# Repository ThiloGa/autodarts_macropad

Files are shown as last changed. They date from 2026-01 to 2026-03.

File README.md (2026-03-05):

<div align="center">
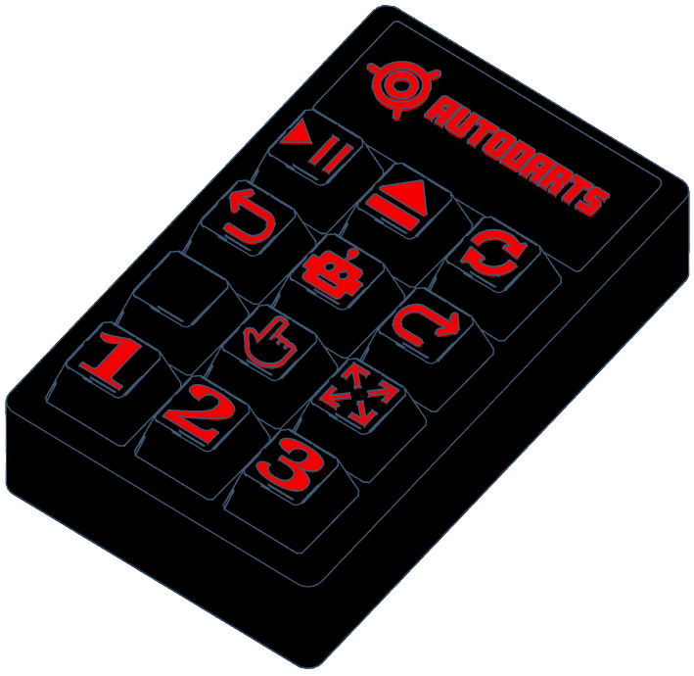
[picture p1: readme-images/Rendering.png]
3D-Modell
    
  
  <h1>🎯 Macropad for Autodarts</h1>
  <p><b>✨ The ultimate DIY wireless companion for your Autodarts setup ✨</b></p>
  <p><i>A custom 12-key controller designed for seamless darts tracking.</i></p>

  <p>
    The Macropad for Autodarts is a wireless DIY controller featuring 12 mechanical keys, specifically designed for comfortable operation of the Autodarts software directly from the oche. It provides instant access to functions such as undoing throws, switching cameras, or calling the AI referee, while offering an impressive battery life of about six weeks via Bluetooth. Thanks to its open-source firmware, the entire device is fully customizable to suit your personal needs.
  </p>

  <p>
    
    
    
  </p>

  <p>
    <a href="#features-en">🚀 Features</a> •
    <a href="#manual-en">📖 Manual</a> •
    <a href="#diagrams-en">🗺️ Wiring & Pinout</a> •
    <a href="#keymap-en">🎹 Keymap</a> •
    <a href="#bom-en">📦 BOM</a> •
    <a href="#operation-en">💡 Troubleshooting</a> •
    <a href="#support-en">☕ Support</a>
  </p>
</div>

<hr />

<h2 id="features-en">🚀 Key Features</h2>
<ul>
  <li><b>📶 True Wireless:</b> Low-energy Bluetooth 5.0 connectivity via the nRF52840 controller for a cable-free oche. 🎯</li>
  <li><b>🔋 Massive Battery Life:</b> Operates for up to <b>6 weeks</b> on a single charge. The integrated deep-sleep mode further preserves battery life. ⚡</li>
  <li><b>⌨️ Superior Tactile Feedback:</b> 12 mechanical Gateron G Pro 3.0 switches provide a high-quality actuation point for reliable inputs. ⌨️</li>
  <li><b>☁️ Cloud Configuration:</b> Customize your keymap directly in the browser via GitHub Actions—no local coding environment required. ☁️</li>
  <li><b>🖥️ OS Integration:</b> Battery percentage is reported natively and can be viewed in Windows or Linux system settings. 🖥️</li>
</ul>

<hr />

<h2 id="manual-en">📖 Comprehensive Manual</h2>
<p>
  This repository includes a <b>detailed 32-page PDF instruction manual</b>. It covers the entire process: from optimized 3D printing settings and complex matrix soldering to flashing the ZMK firmware and customized key mapping.
  <br><br>
  👉 <b>View the Instructions here:</b> <a href="https://github.com/mrcl-rckl/autodarts_macropad/blob/main/instructions/0_EN_Instructions.pdf">0_EN_Instructions.pdf</a>
  <br>
  👉 <b>3D Models on Printables:</b> <a href="https://www.printables.com/model/1576041-autodarts-macropad">Printables.com</a>
  <br>
  👉 <b>3D Models on MakerWorld:</b> <a href="https://makerworld.com/de/models/2319788-autodarts-macropad">MakerWorld.com</a>
</p>

<hr />

<h2 id="bom-en">📦 Bill of Materials (BOM)</h2>
<p>This project is designed for experienced makers and involves 3D printing, component assembly, and precision soldering. 🛠️</p>
<table>
  <thead>
    <tr>
      <th>Qty</th>
      <th>Component 🛒</th>
      <th>Source 🔗</th>
    </tr>
  </thead>
  <tbody>
    <tr>
      <td>12x</td>
      <td><b>Gateron G Pro 3.0 Switches</b></td>
      <td><a href="https://de.aliexpress.com/item/1005007052507996.html">AliExpress</a></td>
    </tr>
    <tr>
      <td>1x</td>
      <td><b>nRF52840 Developer Board (SuperMini)</b></td>
      <td><a href="https://de.aliexpress.com/item/1005008664621573.html">AliExpress</a></td>
    </tr>
    <tr>
      <td>1x</td>
      <td><b>500mAh LiPo Battery (503030)</b></td>
      <td><a href="https://de.aliexpress.com/item/1005007964712378.html">AliExpress</a></td>
    </tr>
    <tr>
      <td>12x</td>
      <td><b>1N4148 Diodes</b></td>
      <td><a href="https://de.aliexpress.com/item/1005006208000285.html">AliExpress</a></td>
    </tr>
    <tr>
      <td>16x</td>
      <td><b>Jumper Wires Female (20-30cm)</b></td>
      <td><a href="https://de.aliexpress.com/item/1005007046465880.html">AliExpress</a></td>
    </tr>
    <tr>
      <td>1x</td>
      <td><b>Toggle Switch (MTS-101)</b></td>
      <td><a href="https://de.aliexpress.com/item/1005009744920784.html">AliExpress</a></td>
    </tr>
    <tr>
      <td>1x</td>
      <td><b>ASUS USB-BT500 Bluetooth Dongle</b></td>
      <td><a href="https://www.cyberport.de/pc-und-zubehoer/netzwerk/bluetooth/asus/pdp/4e18-007/asus-usb-bt500-bluetooth-5-0-usb-adapter.html">Cyberport</a></td>
    </tr>
  </tbody>
</table>

<h3>🛠️ Required Tools & Additional Materials</h3>
<ul>
  <li>USB-C charging cable</li>
  <li>Soldering iron & Solder wire</li>
  <li>Hot air gun or lighter (for insulation)</li>
  <li>Heat shrinks & side cutters</li>
  <li>Pliers & wire stripping tool</li>
  <li>Super glue (for mounting logos)</li>
  <li>Filament (PLA or PETG - 2 colors recommended)</li>
</ul>

<hr />

<h2 id="diagrams-en">🗺️ Wiring Diagram & Pinout</h2>
<div align="center">
  <h3>🛠️ Wiring Diagram</h3>
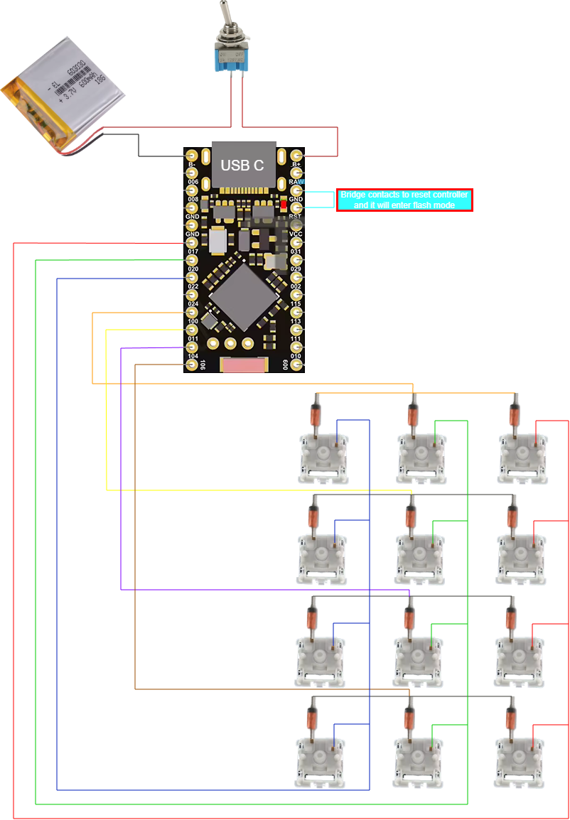
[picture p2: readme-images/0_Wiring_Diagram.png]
Wiring Diagram
  
  <br><br>
  <h3>🔌 Controller Pinout</h3>
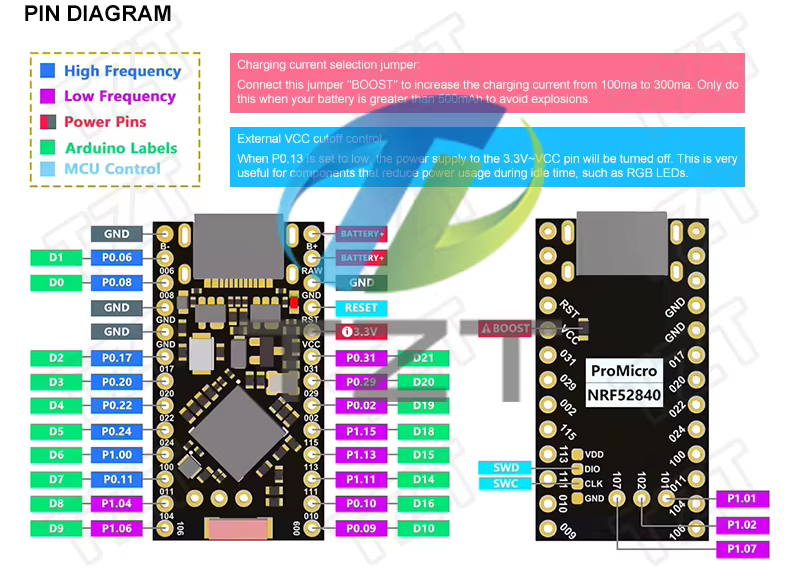
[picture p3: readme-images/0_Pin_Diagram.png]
Pin Diagram
  
</div>

<hr />

<h2 id="keymap-en">🎹 Default Key Assignment</h2>
<p>The layout is fully optimized for the Autodarts web interface commands. 🎯</p>

<div align="center">
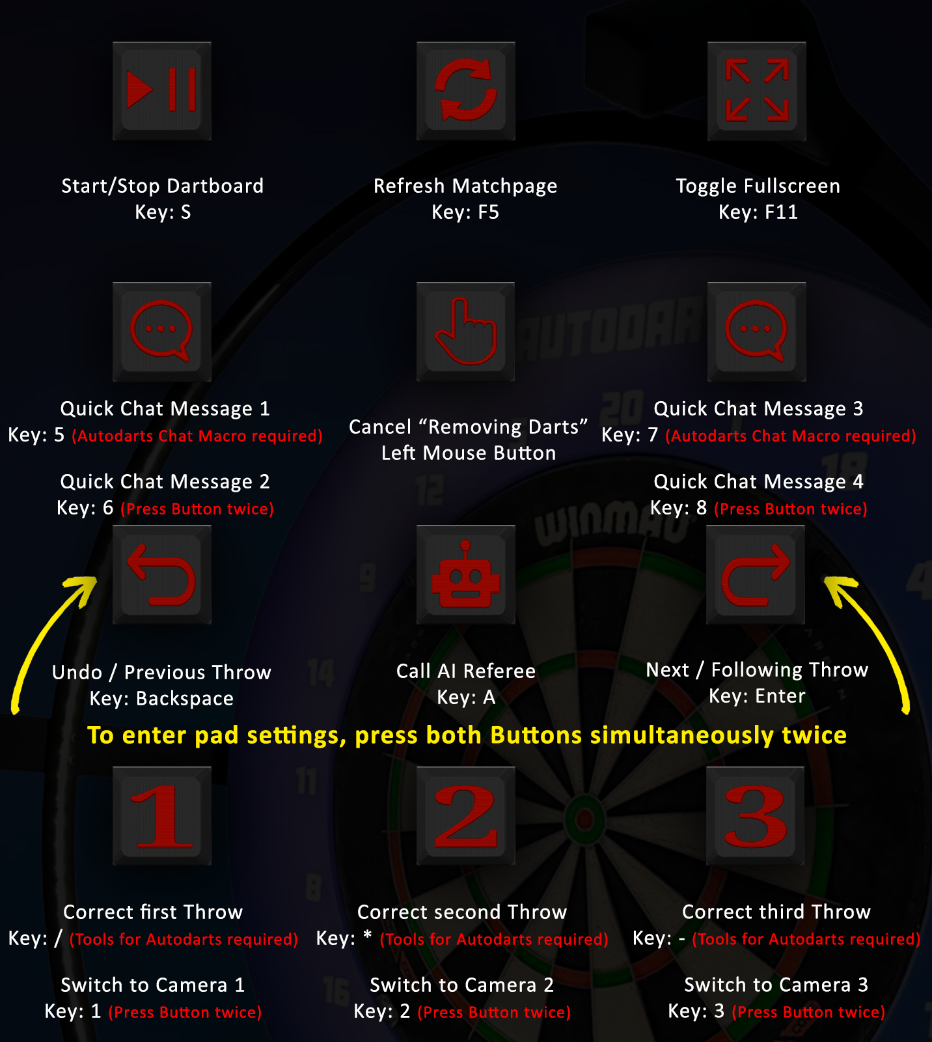
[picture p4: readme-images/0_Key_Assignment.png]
Keymap Assignment
  
</div>

<div align="center">
  Quick Corretion
</div>

<div align="center">
  Settings
</div>

<br>

<hr />

<h2 id="operation-en">💡 Operation & Troubleshooting</h2>
<ul>
  <li><b>Charging:</b> The physical toggle switch <b>MUST be in the ON position</b> to charge the battery via USB-C. 🔌</li>
  <li><b>Pairing Reset:</b> To clear existing Bluetooth bonds, press <b>[Arrow Left] + [Arrow Right]</b> keys simultaneously twice. 🔄</li>
  <li><b>Bootloader Mode:</b> If the device is not recognized as a drive, bridge the <b>GND</b> and <b>RST</b> pins twice quickly while connected to the PC. 💾</li>
  <li><b>Input Focus:</b> Ensure the browser window is "in focus" (clicked) for Autodarts to register key presses. 🎯</li>
</ul>

<hr />

<h2 id="support-en">☕ Support</h2>
<p align="left">
  If this project helped you hit the bullseye, consider supporting my work! 🎯☕
  <br><br>
  <a href="https://www.buymeacoffee.com/mrcl_rckl">
    Buy Me A Coffee
  </a>
</p>

<hr />
<br><br>

<br><br>
<hr />

<div align="center">
  <h1>🎯 Zusatztastatur für Autodarts</h1>
  <p><b>✨ Der ultimative kabellose Begleiter für dein Autodarts-Setup – Marke Eigenbau ✨</b></p>
  <p><i>Ein maßgeschneidertes 12-Tasten-Steuergerät für die professionelle Wurferfassung am Oche.</i></p>

  <p>
    Das Macropad für Autodarts ist ein kabelloses DIY-Steuergerät mit 12 mechanischen Tasten, das speziell für die komfortable Bedienung der Autodarts-Software direkt am Oche entwickelt wurde. Es ermöglicht den blitzschnellen Zugriff auf Funktionen wie Wurfrücknahme, Kamerawechsel oder den KI-Schiedsrichter und bietet dank Bluetooth-Anbindung eine beachtliche Akkulaufzeit von etwa sechs Wochen. Durch die Nutzung von Open-Source-Firmware lässt sich das gesamte Gerät zudem vollständig nach deinen persönlichen Wünschen anpassen.
  </p>

  <p>
    
    
    
  </p>

  <p>
    <a href="#features-de">🚀 Funktionen</a> •
    <a href="#manual-de">📖 Anleitung</a> •
    <a href="#diagrams-de">🗺️ Schaltplan & Pinbelegung</a> •
    <a href="#keymap-de">🎹 Tastenbelegung</a> •
    <a href="#bom-de">📦 Stückliste</a> •
    <a href="#operation-de">💡 Fehlerbehebung</a> •
    <a href="#support-de">☕ Unterstützung</a>
  </p>
</div>

<hr />

<h2 id="features-de">🚀 Hauptmerkmale</h2>
<ul>
  <li><b>📶 Vollkommen Kabellos:</b> Dank Bluetooth 5.0 und dem nRF52840-Steuermodul bleibt dein Abwurfbereich frei von Kabeln. 🎯</li>
  <li><b>🔋 Enorme Akkulaufzeit:</b> Eine einzige Ladung hält bei normaler Nutzung bis zu <b>6 Wochen</b>. Der integrierte Tiefschlafmodus schont die Batterie zusätzlich. ⚡</li>
  <li><b>⌨️ Hochwertiger Druckpunkt:</b> 12 mechanische Gateron G Pro 3.0 Schalter bieten ein erstklassiges haptisches Feedback und garantieren eine zuverlässige Bedienung. ⌨️</li>
  <li><b>☁️ Cloud-Konfiguration:</b> Die Tastenbelegung kann direkt im Browser über GitHub-Automatisierungen angepasst werden – es ist keine lokale Programmierumgebung erforderlich. ☁️</li>
  <li><b>🖥️ System-Integration:</b> Der Akkustand wird direkt in den Einstellungen von Windows oder Linux angezeigt. 🖥️</li>
</ul>

<hr />

<h2 id="manual-de">📖 Umfangreiche Anleitung</h2>
<p>
  In diesem Projektarchiv findest du eine <b>detaillierte 32-seitige PDF-Anleitung</b>. Diese führt dich Schritt für Schritt durch den gesamten Prozess: von den optimalen Einstellungen für den 3D-Druck über das präzise Verlöten der Tastatur-Matrix bis hin zur Installation der Steuersoftware und der persönlichen Tastenbelegung.
  <br><br>
  👉 <b>Hier zur Anleitung:</b> <a href="https://github.com/mrcl-rckl/autodarts_macropad/blob/main/instructions/0_DE_Anleitung.pdf">0_DE_Anleitung.pdf</a>
  <br>
  👉 <b>3D-Modelle auf Printables:</b> <a href="https://www.printables.com/model/1576041-autodarts-macropad">Printables.com</a>
  <br>
  👉 <b>3D-Modelle auf MakerWorld:</b> <a href="https://makerworld.com/de/models/2319788-autodarts-macropad">MakerWorld.com</a>
</p>

<hr />

<h2 id="bom-de">📦 Stückliste</h2>
<p>Dieses Projekt wird für erfahrene Bastler empfohlen, da es fundierte Kenntnisse im 3D-Druck und im Weichlöten voraussetzt. 🛠️</p>
<table>
  <thead>
    <tr>
      <th>Menge</th>
      <th>Bauteil 🛒</th>
      <th>Bezugsquelle 🔗</th>
    </tr>
  </thead>
  <tbody>
    <tr>
      <td>12x</td>
      <td><b>Gateron G Pro 3.0 Tastenschalter</b></td>
      <td><a href="https://de.aliexpress.com/item/1005007052507996.html">AliExpress</a></td>
    </tr>
    <tr>
      <td>1x</td>
      <td><b>nRF52840 Entwickler-Platine (SuperMini)</b></td>
      <td><a href="https://de.aliexpress.com/item/1005008664621573.html">AliExpress</a></td>
    </tr>
    <tr>
      <td>1x</td>
      <td><b>500mAh LiPo Akku (Bauform 503030)</b></td>
      <td><a href="https://de.aliexpress.com/item/1005007964712378.html">AliExpress</a></td>
    </tr>
    <tr>
      <td>12x</td>
      <td><b>1N4148 Dioden</b></td>
      <td><a href="https://de.aliexpress.com/item/1005006208000285.html">AliExpress</a></td>
    </tr>
    <tr>
      <td>16x</td>
      <td><b>Steckbrückenkabel (weiblich, 20-30cm)</b></td>
      <td><a href="https://de.aliexpress.com/item/1005007046465880.html">AliExpress</a></td>
    </tr>
    <tr>
      <td>1x</td>
      <td><b>Kippschalter (MTS-101)</b></td>
      <td><a href="https://de.aliexpress.com/item/1005009744920784.html">AliExpress</a></td>
    </tr>
    <tr>
      <td>1x</td>
      <td><b>ASUS USB-BT500 Bluetooth-Adapter</b></td>
      <td><a href="https://www.cyberport.de/pc-und-zubehoer/netzwerk/bluetooth/asus/pdp/4e18-007/asus-usb-bt500-bluetooth-5-0-usb-adapter.html">Cyberport</a></td>
    </tr>
  </tbody>
</table>

<h3>🛠️ Erforderliche Werkzeuge & Materialien</h3>
<ul>
  <li>USB-C Ladekabel</li>
  <li>Lötkolben & Lötzinn</li>
  <li>Heißluftfön oder Feuerzeug (für die Isolierung der Kontakte)</li>
  <li>Schrumpfschläuche & Seitenschneider</li>
  <li>Zange & Abisolierwerkzeug</li>
  <li>Sekundenkleber (zum Fixieren der Logos)</li>
  <li>Filament (PLA oder PETG - 2 verschiedene Farben für Kontrast-Optik empfohlen)</li>
</ul>

<hr />

<h2 id="diagrams-de">🗺️ Stromlaufplan & Anschlussbelegung</h2>
<div align="center">
  <h3>🛠️ Schaltplan der Tastatur-Matrix</h3>
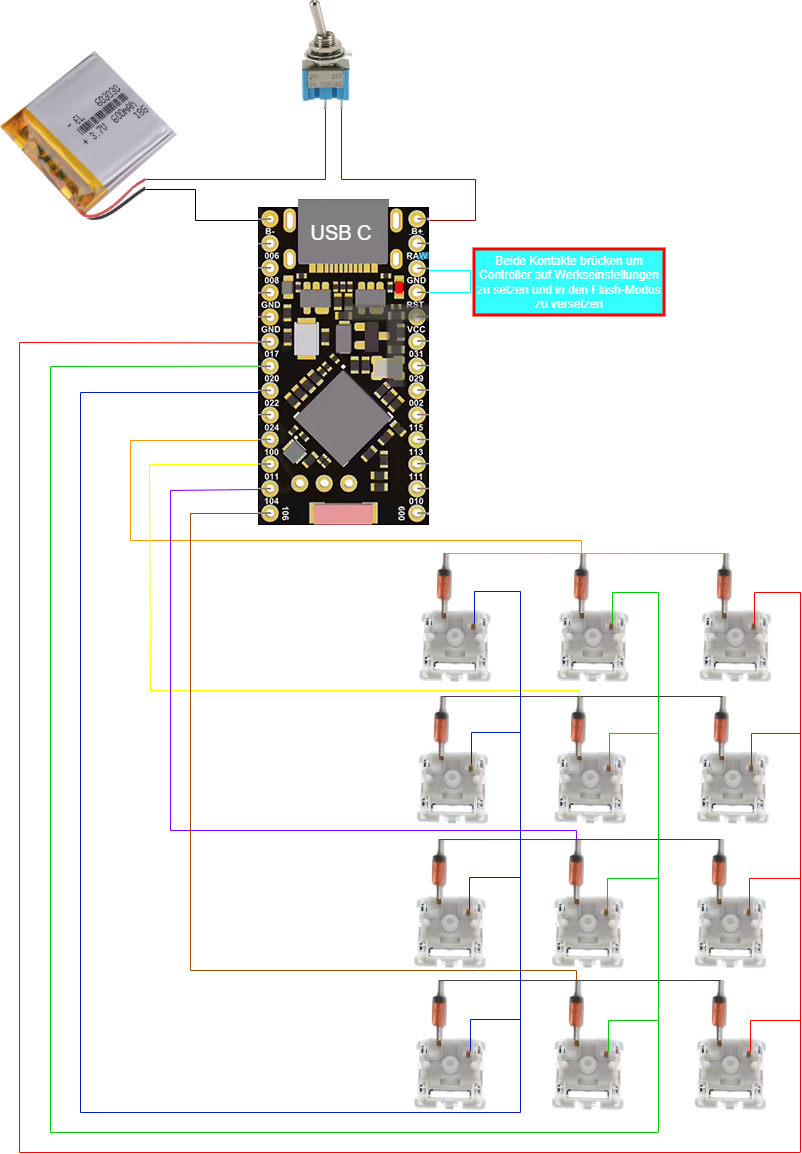
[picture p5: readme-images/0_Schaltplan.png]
Stromlaufplan
  
  <br><br>
  <h3>🔌 Anschlussbelegung des Steuerungsmoduls</h3>
  Anschlussbelegung
</div>

<hr />

<h2 id="keymap-de">🎹 Standard-Tastenbelegung</h2>
<p>Die Tasten sind für die Autodarts-Weboberfläche optimiert, damit du dich voll auf deine Würfe konzentrieren kannst. 🎯</p>

<div align="center">
  Tastenbelegung
</div>

<div align="center">
  Schnell-Korrekur
</div>

<div align="center">
  Einstellungen
</div>

<br>

<hr />

<h2 id="operation-de">💡 Bedienung & Fehlerbehebung</h2>
<ul>
  <li><b>Ladevorgang:</b> Der physische Kippschalter <b>MUSS auf EIN (ON)</b> stehen, damit der Akku über USB-C geladen werden kann. 🔌</li>
  <li><b>Verbindung zurücksetzen:</b> Um die Bluetooth-Kopplung zu löschen, die Tasten <b>[Pfeil Links] + [Pfeil Rechts]</b> gleichzeitig zweimal drücken. 🔄</li>
  <li><b>Bootloader-Modus:</b> Falls die Platine nicht als Laufwerk erkannt wird, überbrücke kurz zweimal hintereinander die Kontakte <b>GND</b> und <b>RST</b>. 💾</li>
  <li><b>Eingabe-Fokus:</b> Das Browserfenster muss aktiv sein („im Fokus“), damit Autodarts die Tastaturbefehle registriert. 🎯</li>
</ul>

<hr />

<h2 id="support-de">☕ Unterstützung</h2>
<p align="left">
  Hat dieses Projekt bei dir ins Schwarze getroffen? Wenn du meine Arbeit unterstützen möchtest, freue ich mich über einen digitalen Kaffee! Jeder Beitrag fließt direkt in die Entwicklung neuer Prototypen und quelloffener Werkzeuge für die Community. 🎯☕
  <br><br>
  <a href="https://www.buymeacoffee.com/mrcl_rckl">
    Spende mir einen Kaffee
  </a>
</p>

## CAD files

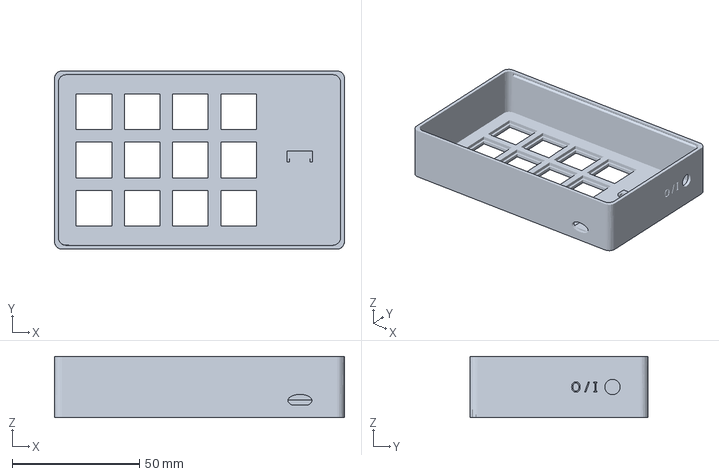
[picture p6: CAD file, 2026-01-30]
3d-printing-files/1_Case.3mf
113.8 x 70.0 x 24.0 mm

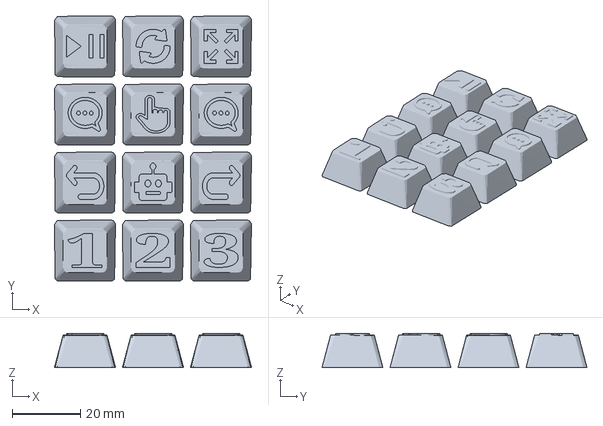
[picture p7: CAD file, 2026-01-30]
3d-printing-files/3_Keycaps_Gateron_Pro_3.3mf
58.0 x 77.9 x 10.0 mm

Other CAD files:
3d-printing-files/1_Case.stl
3d-printing-files/3_Keycaps_Gateron_Pro_3.stl

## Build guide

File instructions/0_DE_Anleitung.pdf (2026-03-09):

Deutsch

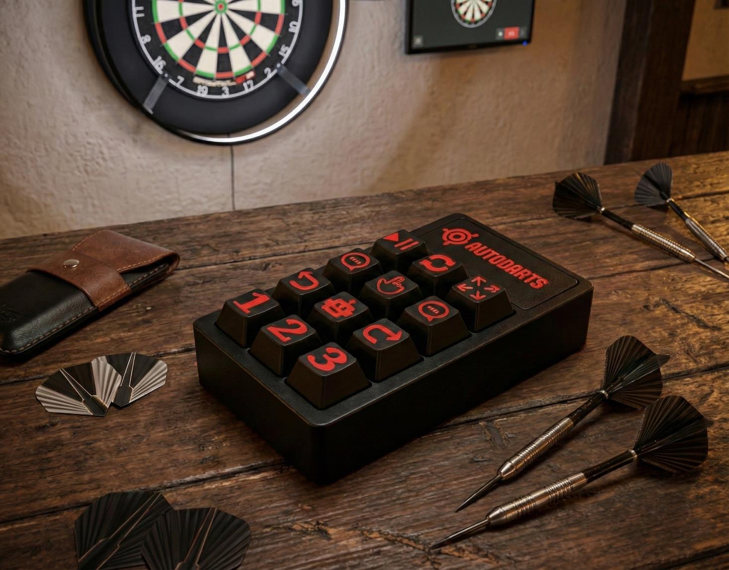
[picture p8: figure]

Autor: mrcl-rckl | 1 | Version: 1.0

# DIY: 12-Tasten-Makropad für Autodarts

Schwierigkeitsgrad: Empfohlen für erfahrene Hersteller

Erfordert 3D-Druck und Löten

Autor: mrcl-rckl | 2 | Version: 1.0

# Inhaltsverzeichnis:

Seite(n) | Inhalt
1 | Titelseite
2 | Inhaltsverzeichnis
3 | Materialliste
4 | Werkzeuge und Zusatzmaterial
5 | 3D-Druck
6-22 | Löten und Montage
23-25 | Installation und Fertigstellung
26-28 | Testen
29-30 | Betriebsanleitung
31-33 | Häufig gestellte Fragen
34 | Firmware-Anpassung
35 | Danke!

Autor: mrcl-rckl | 3 | Version: 1.0

# Materialliste:

- 12x GATERON G Pro 3.0 Schalter: https://de.aliexpress.com/item/1005007052507996.html
- 1x nRF52840 Entwicklerboard (SuperMini): https://de.aliexpress.com/item/1005008664621573.html
- 1x 503030 500mAh Akku (auch größer möglich, da genug Platz ist): https://de.aliexpress.com/item/1005007964712378.html
- 12x 1N4148 Dioden:
https://de.aliexpress.com/item/1005006208000285.html
- 16x Jumper-Drähte weiblich (mindestens 20 cm → 30 cm empfohlen): https://de.aliexpress.com/item/1005007046465880.html
- 1x Kippschalter (nicht notwendig, aber empfohlen für längere Akkulaufzeit im Standby): https://de.aliexpress.com/item/4001252480288.html
- 1x ASUS USB-BT500 Bluetooth 5.0 Dongle-Adapter (nicht nötig, wenn das zu koppelnde Gerät bereits über Bluetooth verfügt – jedoch trotzdem empfohlen, um durch BLE den Akku zu schonen): https://www.cyberport.de/pc-undzubehoer/netzwerk/bluetooth/asus/pdp/4e18-007/asus-usb-bt500-bluetooth-5-0-usb-adapter.html (https://www.cyberport.de/pc-und-zubehoer/netzwerk/bluetooth/asus/pdp/4e18-007/asus-usb-bt500-bluetooth-5-0-usb-adapter.html)

Autor: mrcl-rckl | 4 | Version: 1.0

# Benötigte Werkzeuge und zusätzliche Materialien:

- USB-C-Kabel
- Lötzinn
- Lötkolben
- Heißluftfön oder Feuerzeug
- Schrumpfschläuche
- Seitenschneider
- Spitzzange
- Abisolierwerkzeug
- Sekundenkleber
- Filament – PLA oder PETG oder ... (2 verschiedene Farben empfohlen)

Autor: mrcl-rckl | 5 | Version: 1.0

# 3D-Druck:

Beginne damit, alle bereitgestellten Modelle auszudrucken. Wenn du einen Bambu-Lab-Drucker verwendest, empfehle ich, die beiliegenden .3mf-Dateien zu verwenden, um bessere Druckergebnisse zu erzielen.

Um einen zweifarbigen Druck zu erzielen, ist kein Mehrfarben-Drucker (mit bspw. AMS) erforderlich. Du kannst einfach eine manuelle Pause oder einen Befehl 'Filament Change' in deinen Slicer auf der gewünschten Schichtenhöhe einfügen. Siehe: https://youtu.be/tKPWpWb8gBw. Der Drucker hält an der angegebenen Stelle an, sodass du das Filament austauschen und den Druck fortsetzen kannst.

Um die beste Druckqualität zu gewährleisten, solltest du den Drucker nicht mit allen Modellen gleichzeitig befüllen. Ich empfehle, die Drucke wie folgt zu gruppieren:

- Charge 1: Hauptgehäuse und die Rückseite
- Charge 2: Alle 12 Tastenkappen (können miteinander gedruckt werden)
- Charge 3: Die optionale Wandhalterung sollte ebenfalls eigenständig gedruckt werden

Dateien auf Printables: https://www.printables.com/model/1576041-autodarts-macropad (https://www.printables.com/model/1576041-autodarts-macropad)

Dateien auf MakerWorld: https://makerworld.com/de/models/2319788-autodarts-macropad (https://makerworld.com/de/models/2319788-autodarts-macropad)

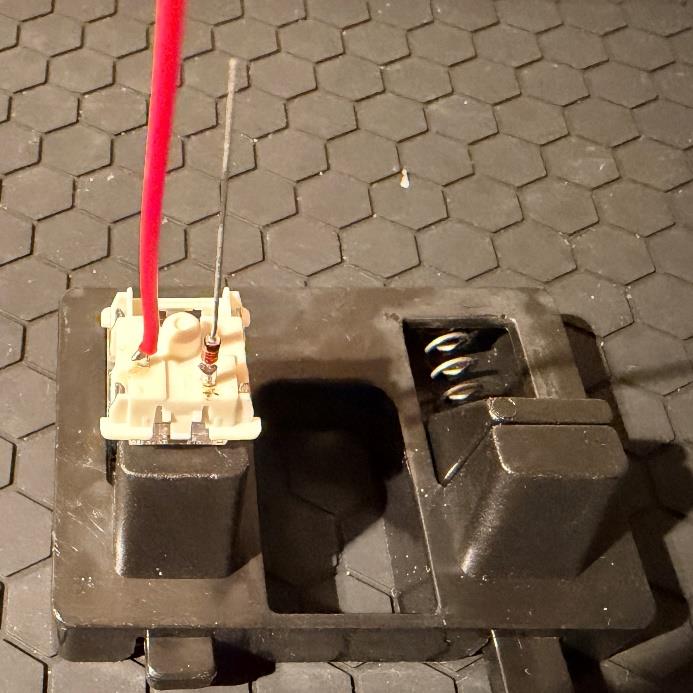
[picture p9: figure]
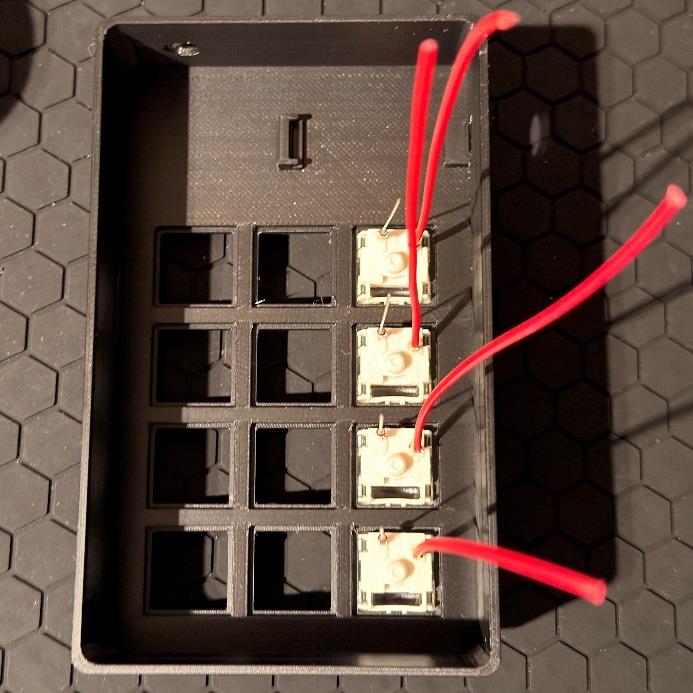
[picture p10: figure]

Autor: mrcl-rckl | 6 | Version: 1.0

# Löten und Montage:

1. Für die ersten vier Tasten beginnt man damit, eine 15 cm lange rote Leitung an einen der Kontaktstifte zu löten. Am gegenüberliegenden Pin wird eine 1N4148-Diode angelötet.
KRITISCH: Richte die Diode so aus, dass der schwarze Strich von der Taste weg zeigt.
2. Die vier vorgelöteten Tasten in das Gehäuse vertikal angeordnet einrasten, um die erste Spalte zu bilden. Stelle sicher, dass jede Taste fest sitzt.

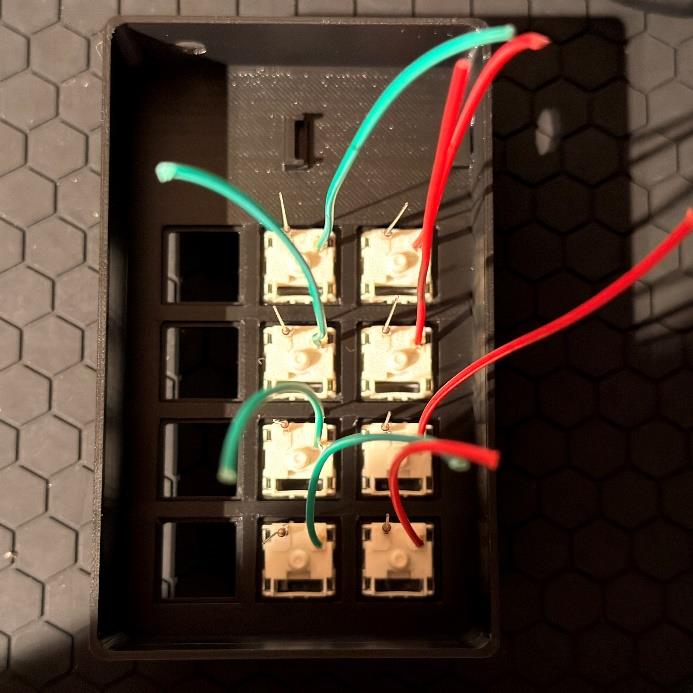
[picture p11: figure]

Autor: mrcl-rckl | 7 | Version: 1.0
3. Für die nächsten vier Tasten beginnt man damit, eine 15 cm lange grüne Leitung an einen der Kontaktstifte zu löten. Am gegenüberliegenden Pin wird eine 1N4148-Diode angelötet.
KRITISCH: Richte die Diode so aus, dass der schwarze Strich von der Taste weg zeigt.
4. Die vier vorgelöteten Tasten in das Gehäuse vertikal angeordnet einrasten, um die mittlere Spalte zu bilden. Stelle sicher, dass jede Taste fest sitzt.

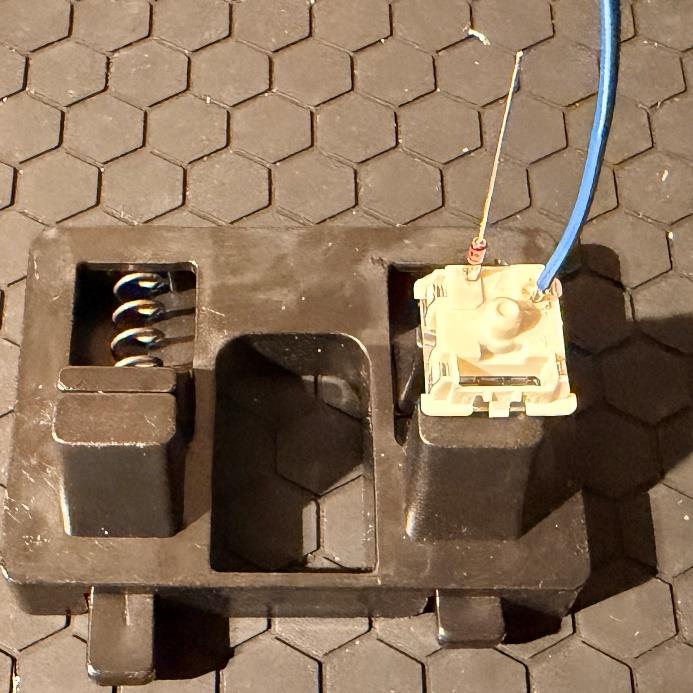
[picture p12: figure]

Autor: mrcl-rckl | 8 | Version: 1.0
5. Für die letzten vier Tasten beginnt man damit, eine 15 cm lange blaue Leitung an einen der Kontaktstifte zu löten. Am gegenüberliegenden Pin wird eine 1N4148-Diode angelötet.
KRITISCH: Richte die Diode so aus, dass der schwarze Strich von der Taste weg zeigt.
6. Die vier vorgelöteten Tasten in das Gehäuse vertikal angeordnet einrasten, um die letzte Spalte zu bilden. Stelle sicher, dass jede Taste fest sitzt.

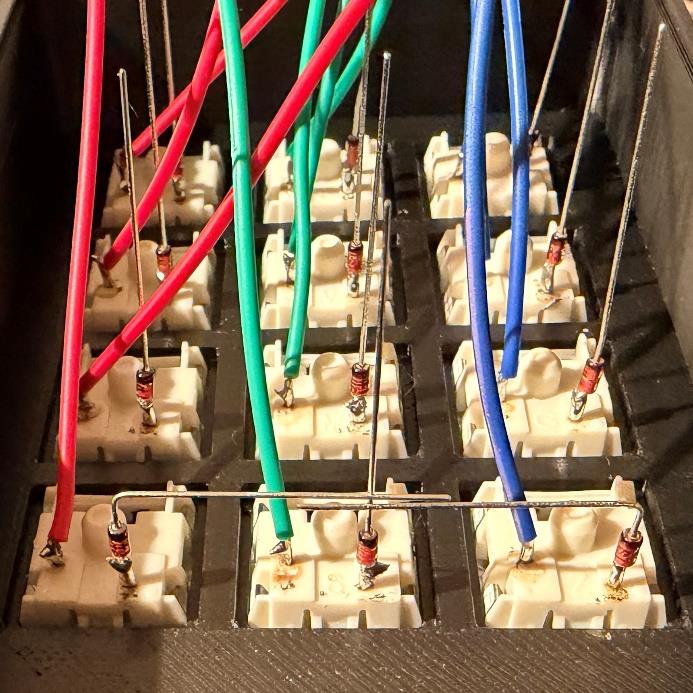
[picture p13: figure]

Autor: mrcl-rckl | 9 | Version: 1.0
7. Identifiziere die oberste Reihe, gekennzeichnet durch den zusätzlichen Platz, der für den nRF52840 reserviert ist. Brücke die drei Dioden, indem du die äußeren Anschlüsse so biegst, dass sie sich an der mittleren Diode überlappen. Die Verwendung einer Spitzzange für diesen Prozess gewährleistet eine zuverlässigere Biegung.
8. Verlöte nun die Verbindung, an der sich die drei Kathodenleitungen treffen. Stelle sicher, dass die Verbindung sauber ist und alle drei Leitungen abdeckt, um einen zuverlässigen Rowbus zu schaffen.

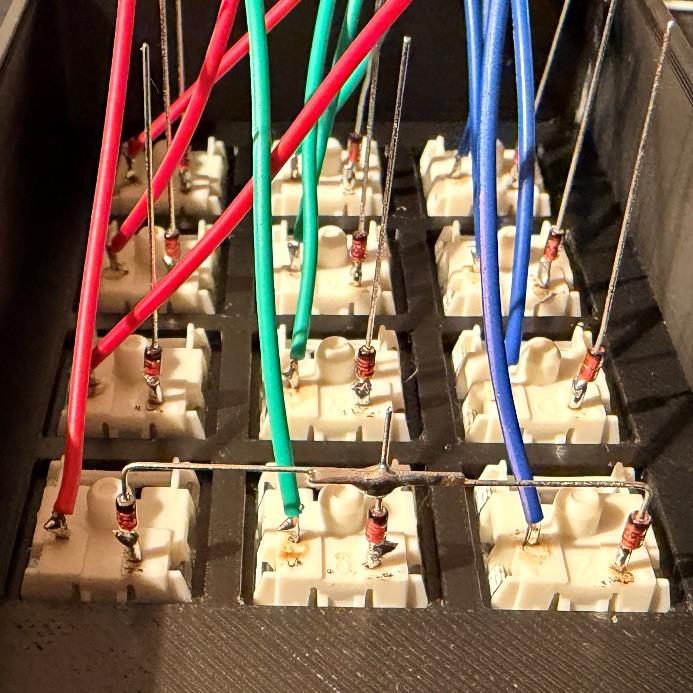
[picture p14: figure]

Autor: mrcl-rckl | 10 | Version: 1.0
9. Verwende einen Seitenschneider um den Draht der mittleren Diode auf etwa 8 mm Länge zu kürzen. So bleibt genug Material für eine sichere Verbindung für das nächste Kabel.
10. Löte ein 20 cm langes orangefarbenes Kabel mit weiblichem Stecker an das getrimmte Ende der Diode. Dieses Kabel dient als Hauptverbindung für deine vertikale Reihe.

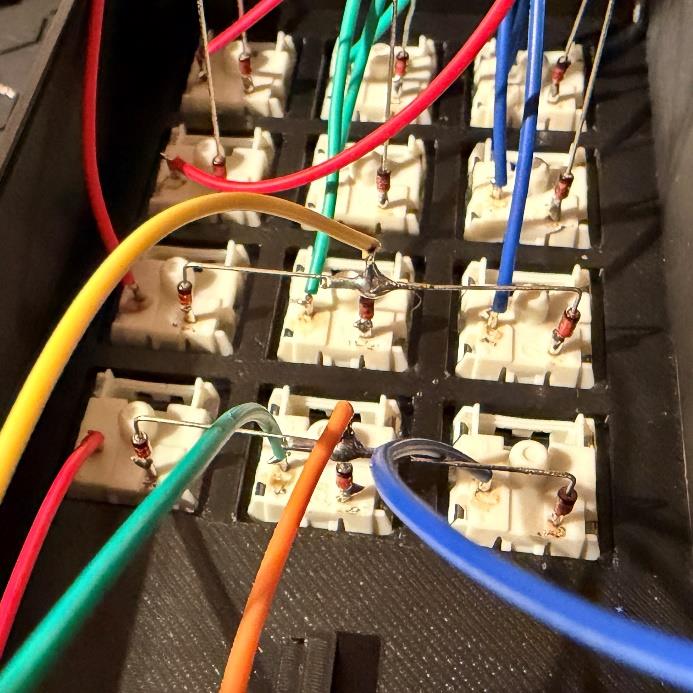
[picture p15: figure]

Autor: mrcl-rckl | 11 | Version: 1.0
11. Wiederhole die Schritte 7 bis 10 für die zweite vertikale Spalte. Ersetze jedoch den orangefarbenen Draht durch einen gelben Draht. Diese Farbunterscheidung hilft, die Reihen während der letzten Verdrahtungsphase korrekt zu identifizieren.
12. Wiederhole die Schritte 7 bis 10 für die zweite vertikale Spalte. Ersetze jedoch den orangefarbenen Draht durch einen violetten Draht. Diese Farbunterscheidung hilft, die Reihen während der letzten Verdrahtungsphase korrekt zu identifizieren.

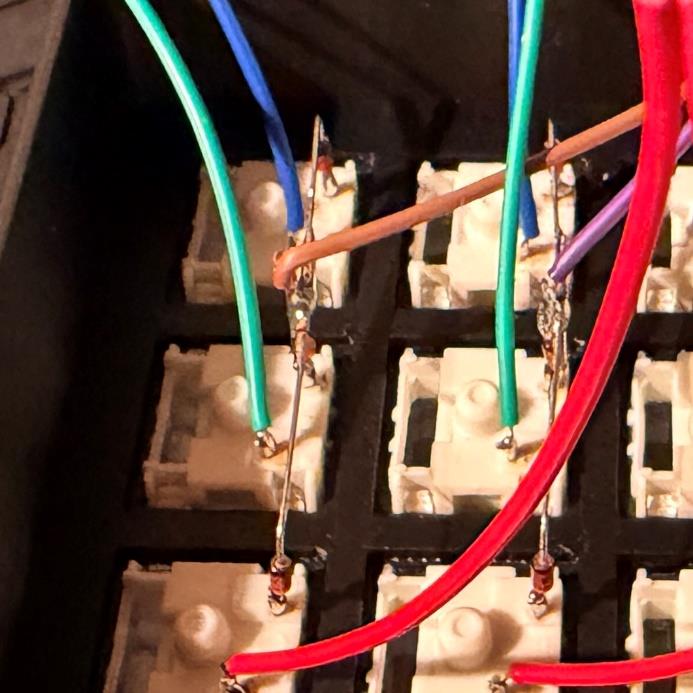
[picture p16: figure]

Autor: mrcl-rckl | 12 | Version: 1.0
13. Wiederhole die Schritte 7 bis 10 für die zweite vertikale Spalte. Ersetze jedoch den orangefarbenen Draht durch einen braunen Draht. Diese Farbunterscheidung hilft, die Reihen während der letzten Verdrahtungsphase korrekt zu identifizieren.
14. Isoliere alle roten Drähte ab und verdrehe die Enden der Kupferstränge zusammen. Löte das Bündel, um einen einzigen, sicheren Abschlusspunkt zu schaffen.

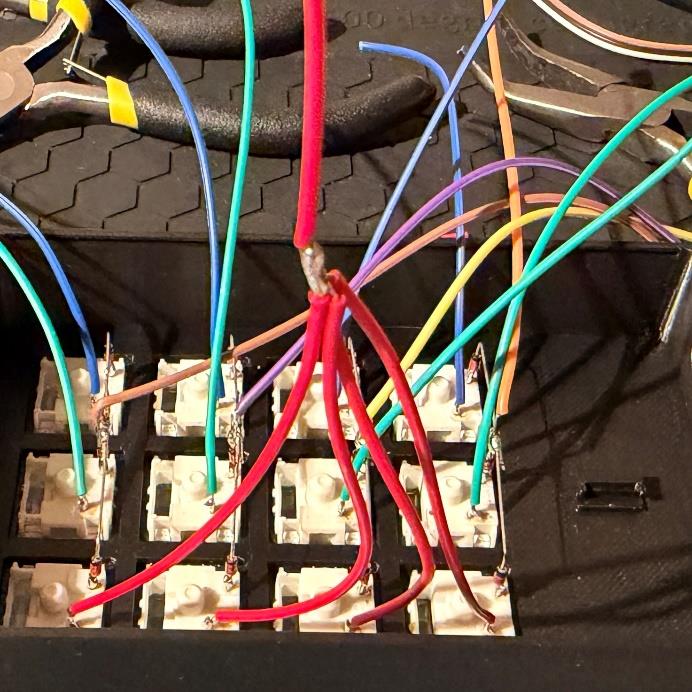
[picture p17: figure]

Autor: mrcl-rckl | 13 | Version: 1.0
15. Bereite ein 15 cm langes rotes Kabel mit einem weiblichen Stecker vor. Schiebe vor dem Löten ein Stück Schrumpfschlauch auf den Draht. Löte das offene Ende dieses Kabels an das rote Drahtbündel, das du im vorherigen Schritt verlötet hast.
16. Schiebe den Schrumpfschlauch über die Lötverbindung. Verwende eine Heißluftpistole oder ein Feuerzeug, um den Schlauch zu schrumpfen, bis es eine feste, sichere Abdichtung um die Verbindung bildet.

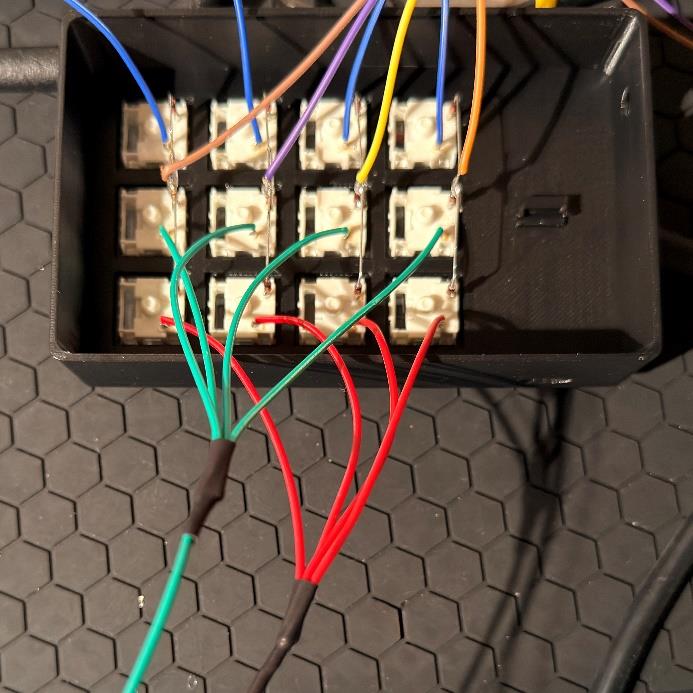
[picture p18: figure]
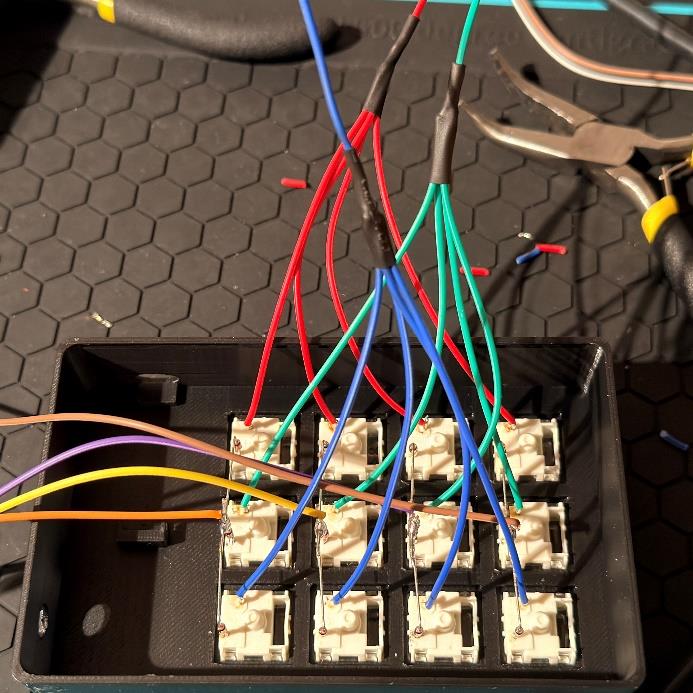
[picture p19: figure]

Autor: mrcl-rckl | 14 | Version: 1.0
17. Wiederhole die Schritte 14–16 mit grünem statt rotem Draht für die mittlere Spalte. Stelle sicher, dass die Lötstelle wie zuvor beschrieben gut mit Schrumpfschlauch isoliert ist.
18. Wiederhole die Schritte 14–16 mit blauem statt rotem Draht für die mittlere Spalte. Stelle sicher, dass die Lötstelle wie zuvor beschrieben gut mit Schrumpfschlauch isoliert ist.

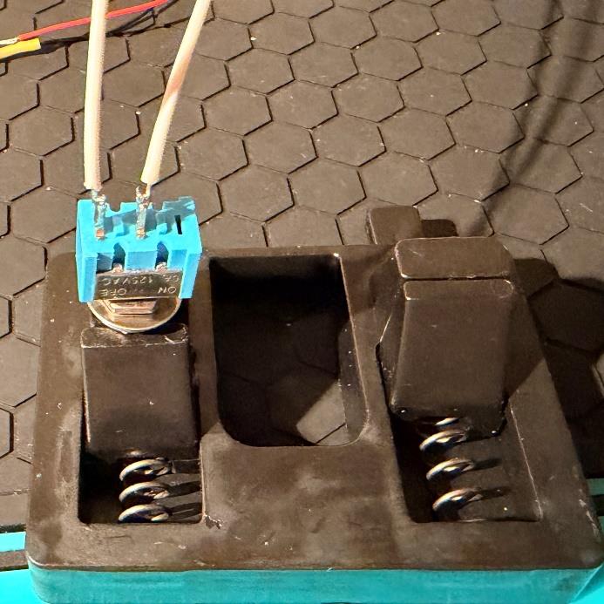
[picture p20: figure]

Autor: mrcl-rckl | 15 | Version: 1.0
19. Bereite den Kippschalter vor, indem ein 30 cm langes weibliches Kabel in zwei Hälften zerschnitten wird. Entferne ein paar Millimeter Isolierung von den abgeschnittenen Enden und schiebe ein Stück Schrumpfschlauch auf jeden Draht. Löte die beiden Leitungen an die Anschlüsse des Kippschalters.
20. Schiebe den Schlauch über die Lötstellen und schrumpfe sie mit einer Heißluftpistole oder einem Feuerzeug für eine vollständig isolierte Verbindung.

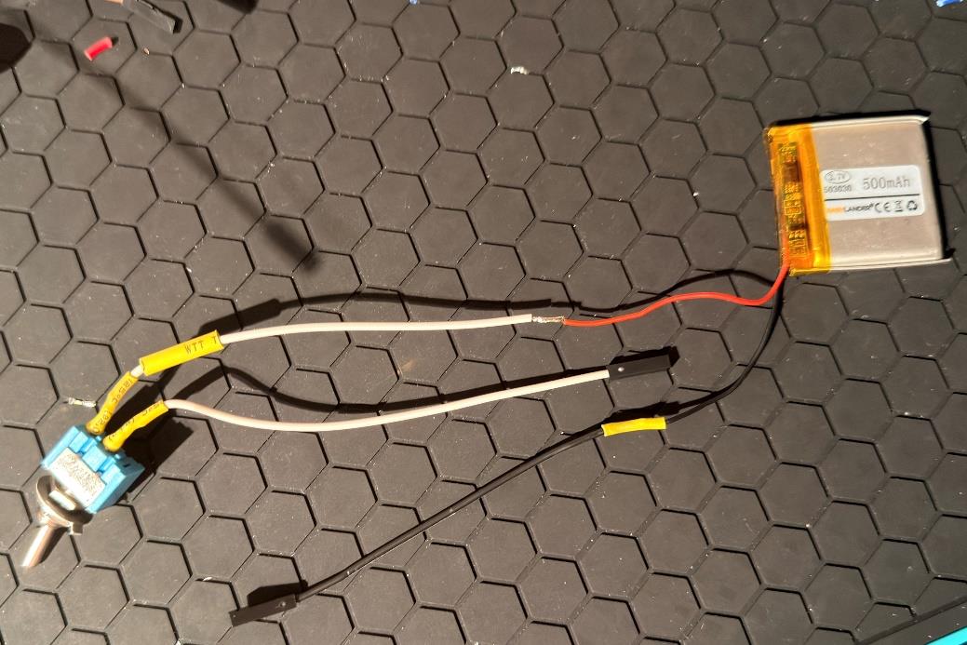
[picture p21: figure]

Autor: mrcl-rckl | 16 | Version: 1.0

21.
a. Vorbereitung der Batterie: Wenn deine Batterie einen Stecker hat, schneide ihn ab. WARNUNG: Schneide die Drähte einzeln durch, um einen Kurzschluss zu verhindern. Lasse die freiliegenden Enden nicht gegenseitig berühren!
b. Kippschalter anschließen: Isoliere die Enden des roten Batteriekabels und das Kabel des Kippschalters ab. Schieben ein Stück Schrumpfschlauch auf das rote (positive) Kabel der Batterie und löte es dann an die Kippschalterleitungen.
c. Batterie-Masseverlängerung: Nimm ein 15 cm langes schwarzes weibliches Jumper-Kabel. Entferne die Isolierung am Ende und mache dasselbe mit der negativen (schwarzen) Leitung der Batterie. Schiebe Schrumpfschlauch vor dem Löten auf das Kabel. Verbinde die beiden schwarzen Drähte und löte sie zusammen, um eine solide Verbindung herzustellen.
d. Isolierung: Positioniere beide Schrumpfschläuche über den Lötstellen und schrumpfe sie mit heißer Luft oder einem Feuerzeug, um die Verbindungen vollständig zu isolieren.

Autor: mrcl-rckl | 17 | Version: 1.0
22. Mikrocontroller auspacken und löte die mitgelieferten männlichen Header-Pins an die Platine. Stelle sicher, dass die Pins perfekt senkrecht sind und die Lötstellen sauber sind, da dies die Verbindungspunkte für alle Ihre weiblichen Drähte sind.

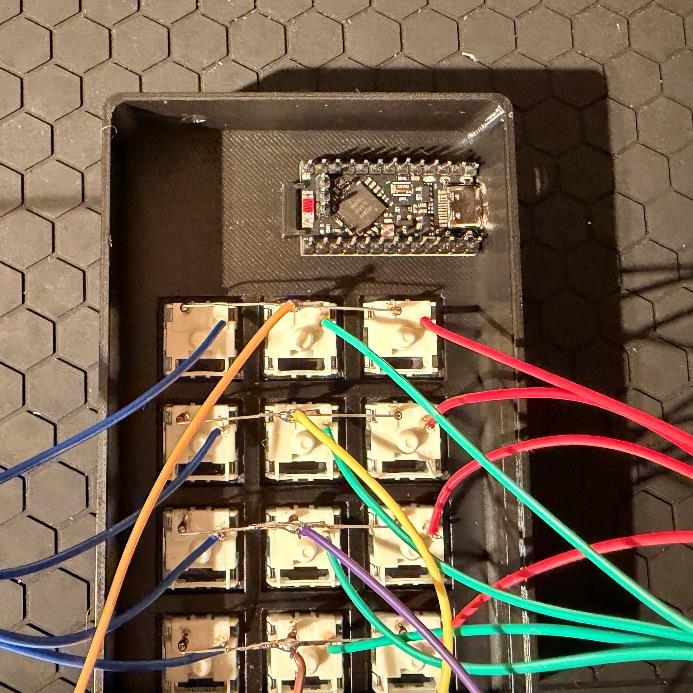
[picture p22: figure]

Autor: mrcl-rckl | 18 | Version: 1.0
23. Setze den Controller in das Gehäuse, indem du ihn mit den beiden Sicherungsklammern in der Mitte des Gehäuses ausrichtest. Du musst in der Nähe des USB-C-Anschlusses kräftigen Druck ausüben, um die Platine nach unten zu schieben, bis der Anschluss perfekt mit der Gehäuseöffnung ausgerichtet ist.
Hinweis: Du musst den Controller möglicherweise vorsichtig bewegen, um die perfekte Position zu finden. Achte darauf, keine übermäßige Kraft anzuwenden, um das MCU oder die 3D-gedruckten Befestigungslaschen nicht zu beschädigen.

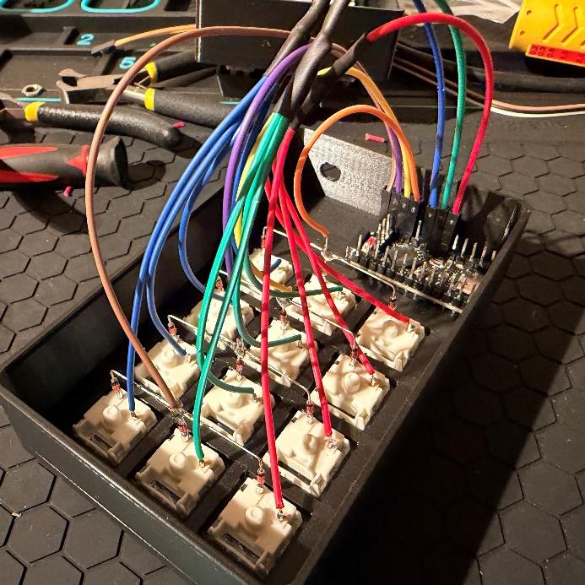
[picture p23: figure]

Autor: mrcl-rckl | 19 | Version: 1.0
24. Schließe nun die weiblichen Jumper gemäß dem bereitgestellten Schaltplan und den Pinout-Bildern an die Header-Pins des Controllers an.

Wichtig: Überprüfe nochmal, ob jede Reihe- und Spaltenleitung mit ihrem zugewiesenen GPIO-Pin verbunden ist. Ein einzelner vertauschter Draht führt zu falschen Tastendrücken oder einer nicht reagierenden Matrix.

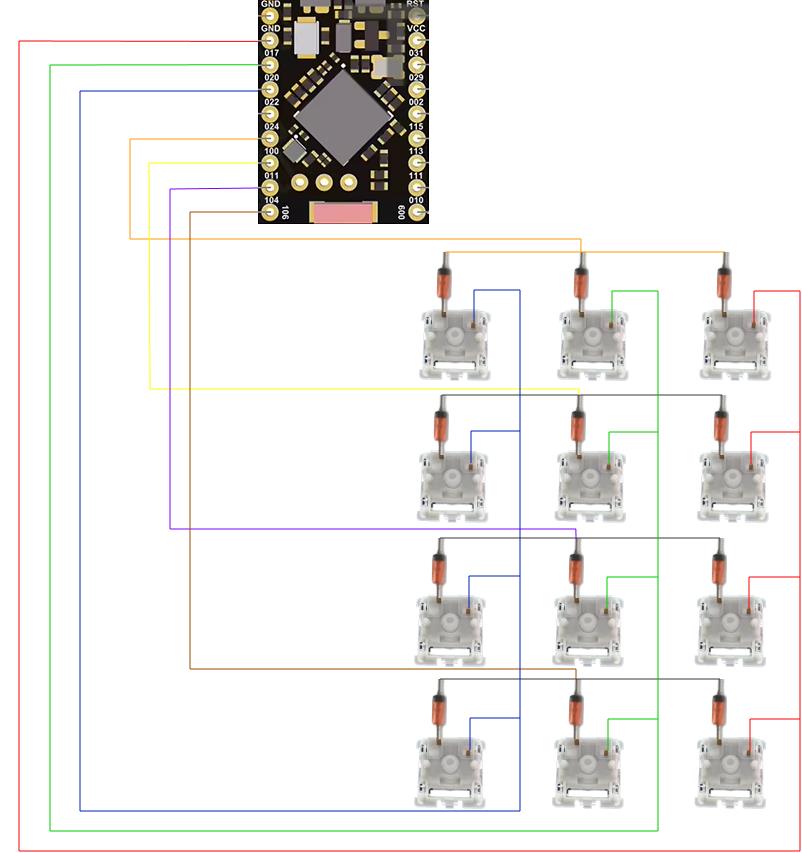
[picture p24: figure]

Autor: mrcl-rckl | 20 | Version: 1.0

Autor: mrcl-rckl | 21 | Version: 1.0
25. Installiere den Kippschalter in das vorgesehene Befestigungsloch im Gehäuse. Verbinde die weiblichen Anschlüsse (schwarz und weiß) mit den Batteriepads (B+ und B-) des Mikrocontrollers, wie im Referenzbild gezeigt. Wichtig: Überprüfe die Polarität vor der Verbindung. Das Vertauschen der Batterieleitungen kann den Ladekreis von nRF52840 dauerhaft beschädigen.

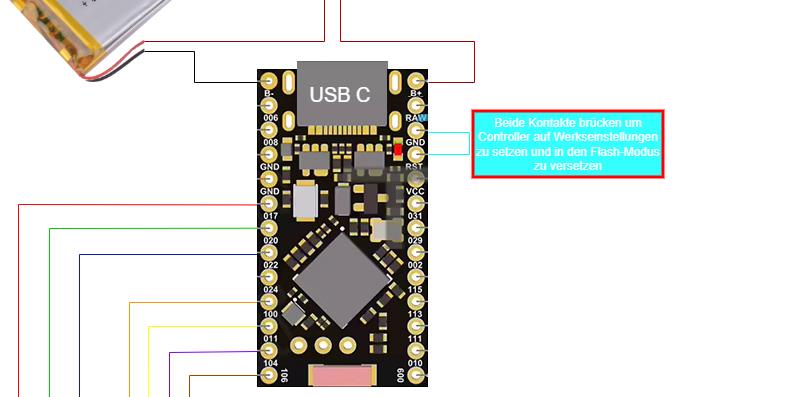
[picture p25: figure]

Autor: mrcl-rckl | 22 | Version: 1.0

26.
a. Interner Leistungstest: Schalte den Kippschalter auf EIN. Die Onboard-Status-LEDs sollten sofort leuchten.
b. USB-Verbindung: Schalte den Schalter AUS und verbinde den Controller per USB-C mit deinem Computer. Die LEDs leuchten wieder, und dein PC sollte das Gerät als Laufwerk erkennen (z. B. NICENANO). Fehlerbehebung: > Wenn das Laufwerk nicht erscheint, musst du möglicherweise manuell den Bootloader-Modus auslösen: Verbinde das USB-Kabel und stelle sicher, dass der Power-Schalter AUS ist. Verwende einen Schraubendreher oder eine Pinzette, um die GNDund RST-Pins vorsichtig zweimal nacheinander zu brücken. VORSICHT: Sei äußerst präzise. Die falschen Pins zu überbrücken könnten einen Kurzschluss verursachen und das MCU dauerhaft beschädigen.

27.

Autor: mrcl-rckl | 23 | Version: 1.0
a. Firmware installieren: Ziehe einfach die Datei
6_Macropad_Firmware.uf2 (hier herunterladen: https://github.com/mrcl-rckl/autodarts_macropad/releases/download/Autodarts/6_Macropad_Firmware.uf2) (https://github.com/mrcl-rckl/autodarts_macropad/releases/download/Autodarts/6_Macropad_Firmware.uf2) auf das Laufwerk des Controllers.
b. Auto-Neustart: Das MCU flasht automatisch die Firmware und startet neu. Das Laufwerk trennt sich und verschwindet von deinem Computer. Hinweis: Um in Zukunft neu zu flashen, musst du manuell erneut in den Bootloader-Modus wechseln, indem Sie du GND- und RST-Pins zweimal nacheinander brückst.
c. Bluetooth-Koppelung: Ziehe das USB-C-Kabel ab und schalte den Power-Schalter auf EIN. Dein Makropad ist jetzt als Bluetooth-Tastatur in den Einstellungen deines Autodarts-Systems erkennbar.

28.
a. Hinweis zur Energieverwaltung: Um die Lebensdauer des Akkus zu erhalten, stelle sicher, dass das Gerät immer über den Kippschalter ausgeschaltet wird, wenn es nicht genutzt wird.
b. Ladeanweisungen: Um die Batterie zu laden, muss der Kippschalter in der EIN-Position stehen. Wenn der Schalter aus ist, wird der Ladekreis getrennt und die Batterie erhält keinen Strom vom USB-C-Anschluss.
c. Akkulaufzeit-Effizienz: Dank des niedrigen Stromverbrauchs des nRF52840 ist die Batterie so ausgelegt, dass sie bei einer einzigen Ladung unter normalen Nutzungsbedingungen etwa 6 Wochen hält.

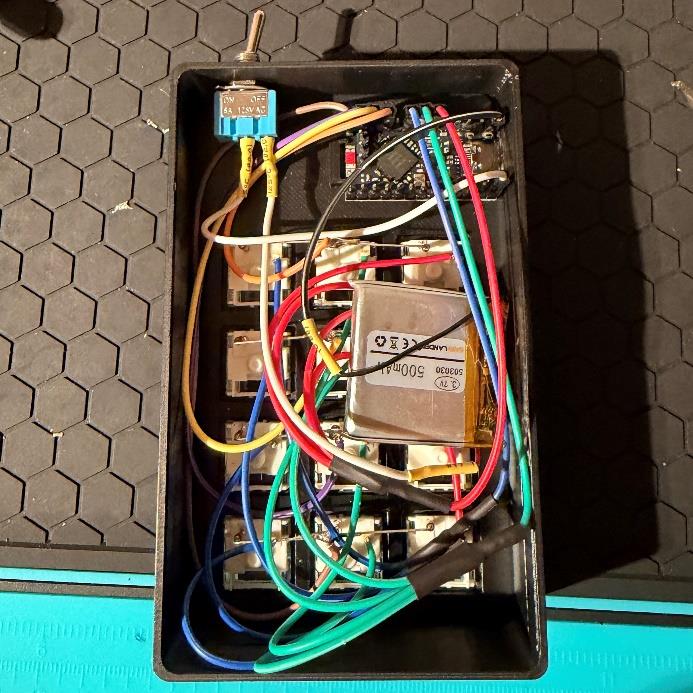
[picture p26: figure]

Autor: mrcl-rckl | 24 | Version: 1.0
29. Setze die Batterie vorsichtig in ihr vorgesehenes Fach im Gehäuse. Stelle sicher, dass alle Drähte ordentlich verstaut sind, um ein Einklemmen zu vermeiden. Zum Schluss richte den Rückdeckel aus und klicke ihn ein, um das Autodarts Macropad zu vervollständigen.
30. Setze die 12 Tastenkappen fest auf die Schalter, indem du sie fest auf die Tasten drückst. Stelle sicher, dass du die richtige Layout-Reihenfolge befolgst, die zu deiner Firmware-Belegung und der Autodarts-Oberfläche passt.

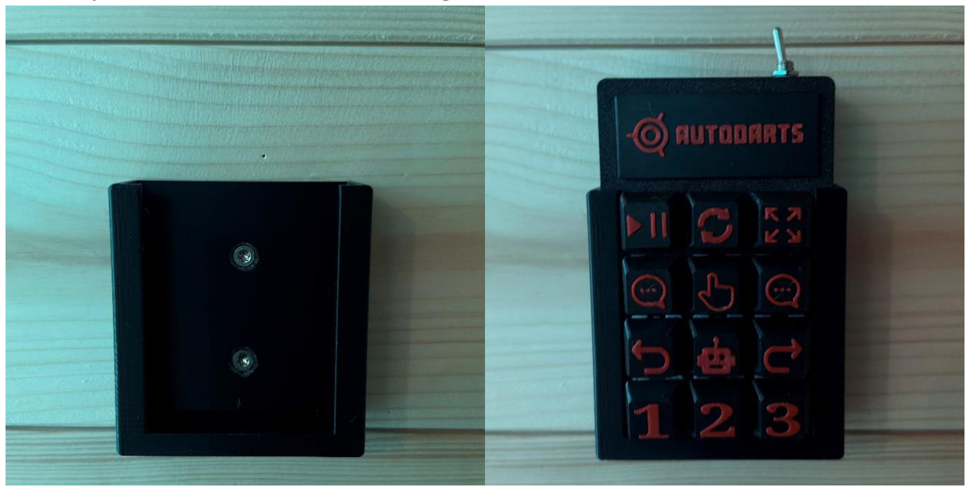
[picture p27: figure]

Autor: mrcl-rckl | 25 | Version: 1.0
31. Zu guter Letzt: Befestige die Wandhalterung mit den passenden Schrauben an der Wand. Sobald die Halterung befestigt ist, schiebe das Makropad einfach in die Halterung, bis es fest sitzt und einsatzbereit ist.

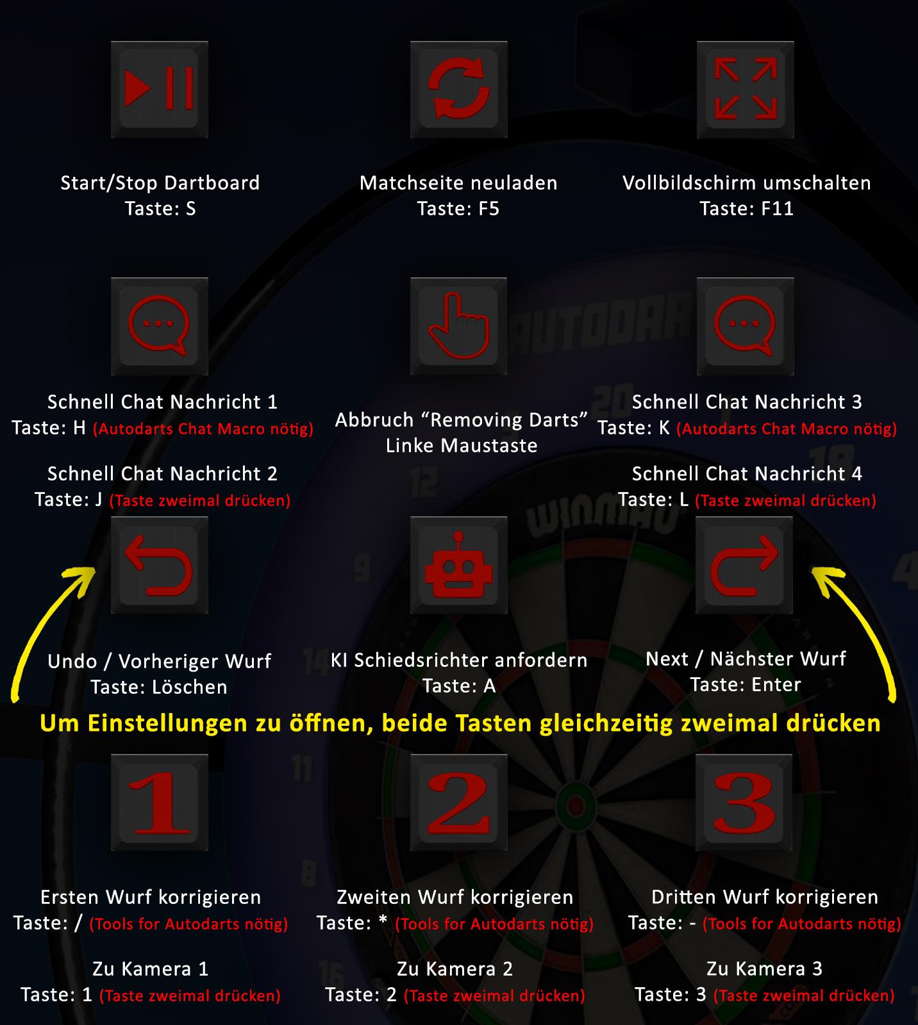
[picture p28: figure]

Autor: mrcl-rckl | 26 | Version: 1.0

# Test:

Siehe das folgende Bild für die spezifischen Tastenzuweisungen. Um zu überprüfen, dass jede Taste korrekt funktioniert und mit dem richtigen Befehl zugeordnet ist, navigiere zum Online-Tastaturtester und drücke jede Taste auf deinem neuen Makropad: https://www.onlinemictest.com/de/tastatur-test/

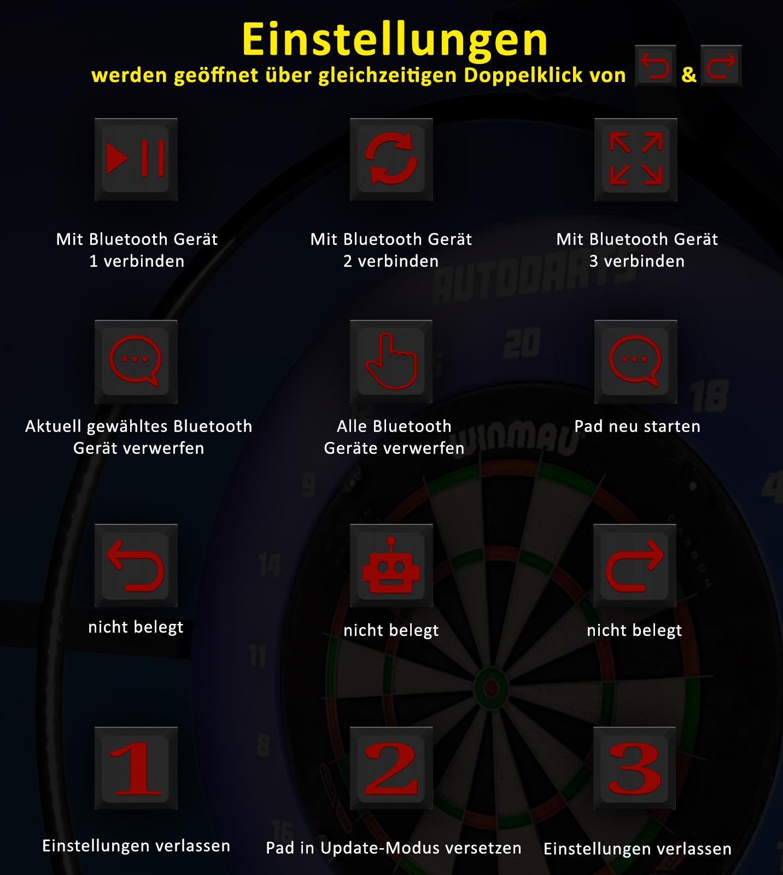
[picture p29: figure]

Autor: mrcl-rckl | 27 | Version: 1.0

Autor: mrcl-rckl | 28 | Version: 1.0

Autor: mrcl-rckl | 29 | Version: 1.0

# Betriebsleitfaden:

1. Ein- und Ausschalten des Geräts: Benutze den physischen Kippschalter an der Seite/Rückseite des Gehäuses. Energieeinsparung: Um die Lebensdauer des Akkus zu maximieren, wird empfohlen, das Gerät bei Nichtbenutzung auszuschalten, obwohl der nRF52840 einen Energiesparmodus im Tiefschlafmodus bietet.
2. Überwachung des Batteriestands: Das Autodarts Macropad meldet seinen Akkustand direkt an Ihr Betriebssystem über das Bluetooth-HID-Profil. Du musst dich nicht auf interne LEDs verlassen. Unter Windows (11/10): Navigiere zu Einstellungen > Bluetooth und Geräte. Finde das "Autodarts Macropad" in der Liste. Der Batterieprozentsatz wird direkt neben dem Gerätenamen angezeigt. Unter Linux (GNOME/KDE): Öffne deine Systemeinstellungen und gehe zum Bereich Strom oder Bluetooth. Der Batteriestatus wird unter "Geräte" oder "Eingabegeräte" angezeigt. Kommandozeile (Fortgeschritten): Du kannst auch den Befehl upower -e verwenden, um den Gerätepfad zu finden, und upower -i [Pfad], um den genauen Prozentsatz zu sehen.
3. Anforderung für Ladeanweisungen: Der Kippschalter muss in der ON-Position sein, um die Batterie zu laden. Wenn der Schalter aus ist, ist der Ladekreis physisch getrennt und der Akku lädt nicht über USB-C auf.
4. Koppeln und Zurücksetzen von Bluetooth: Da das Macropad bis zu drei verschiedene Geräte (z. B. PC, Laptop, Tablet) speichern kann, erfolgt das Verbinden und Wechseln über die versteckte Admin-Ebene.
So aktivierst du den Admin-Modus: Stelle sicher, dass das Gerät EINGESCHALTET ist. Drücke die Tasten [Backspace] und [Enter] gleichzeitig zweimal schnell hintereinander (wie ein Doppelklick). Das Pad schaltet nun für 5 Sekunden in den Admin-Modus. Bluetooth-Gerät wechseln (Profil 1, 2 oder 3): Aktiviere den Admin-Modus und drücke eine der drei obersten Tasten (Reihe 1), um auf Profil 1, 2 oder 3 zu wechseln. Das Pad verbindet sich dann automatisch mit dem dort gespeicherten Gerät.

Autor: mrcl-rckl | 30 | Version: 1.0

Neuen PC koppeln (Profil zurücksetzen): Wenn du das Macropad mit einem neuen Computer verbinden möchtest, musst du das aktuell gewählte Profil zuerst löschen, um den Kopplungsmodus auszulösen: Aktiviere den Admin-Modus (Doppelklick auf Backspace + Enter). Drücke die linke Taste in der zweiten Reihe. Das Gerät leert seinen Speicher für dieses Profil und schaltet sofort in den Kopplungsmodus. Es wird jetzt wieder als neues Gerät in den Bluetooth-Einstellungen deines Systems auffindbar sein.

Autor: mrcl-rckl | 31 | Version: 1.0

# Häufig gestellte Fragen:

Konnektivität & Bluetooth:

F: Die Verbindung fühlt sich verzögert an oder die Tasten wiederholen sich.

A: Bluetooth-Signale können durch Störungen beeinflusst werden. Stelle sicher, dass sich keine großen Metallobjekte oder leistungsstarken 2,4-GHz-Router direkt zwischen dem Pad und Ihrem Computer befinden. Wenn du einen Desktop-PC benutzt, stelle sicher, dass deine Bluetooth-Antenne angeschlossen ist.

Strom & Batterie:

F: Ich habe das Pad seit Stunden an USB-C angeschlossen, aber der Akku ist immer noch leer.

A: Entscheidende Kontrolle: Ist dein Kippschalter EINGESCHALTET? Aufgrund des Hardware-Designs verbindet sich die Batterie nur mit dem Ladekreis, wenn der Schalter in der ON-Position ist. Es lädt nicht, wenn das Gerät ausgeschaltet ist.

F: Das Gerät funktioniert über USB, schaltet sich aber sofort aus, sobald ich das Kabel abziehe.

A: Überprüfe die Lötstellen an den B+- und B-Pins des Mikrocontrollers, sowie an den Batterieleitungen. Stelle außerdem sicher, dass die Verkabelung des Kippschalters korrekt ist. Wenn sich ein Kabel gelöst hat, kann die Batteriestromversorgung das MCU nicht erreichen.

Schlüsseleingaben & Hardware:

F: Eine bestimmte Taste wird überhaupt nicht registriert.

A: Dies ist in der Regel ein Hardwareproblem. Überprüfe die Lötstellen an genau dieser Taste. Überprüfe die Ausrichtung der Diode. Wenn die Diode rückwärts verlötet wird, wird das Signal blockiert. Überprüfe die Verbindung zwischen dem Zeilen-/Spaltenkabel und dem MCU-Pin.

Autor: mrcl-rckl | 32 | Version: 1.0

F: Wenn ich eine Taste drücke, erscheint der falsche Buchstabe auf dem Bildschirm.

A: Deine physische Verkabelung stimmt wahrscheinlich nicht mit den in der Firmware definierten GPIO-Pins überein. Überprüfe deine Verkabelung noch einmal mit dem Schaltplan auf Seite 20. Wenn du ein Zeilen- oder Spaltenkabel vertauscht hast, wird das Layout gespiegelt oder verschoben.

Firmware & Flashing:

F: Der Controller erscheint nicht als "NICENANO" oder "Removable Drive", wenn er eingesteckt ist.

A: Verwende ein anderes USB-C-Kabel; Viele Kabel sind nur auf Ladekabel und übertragen keine Daten. Wenn das Kabel in Ordnung ist, musst du manuell den Bootloader-Modus aktivieren.

F: Ich habe die .uf2-Datei geflasht, aber sich hat sich nichts geändert.

A: Stelle sicher, dass die Dateiübertragung vollständig abgeschlossen ist, bevor das Laufwerk getrennt wurde. Wenn das Laufwerk sofort nach dem Löschen der Datei verschwindet, war der Flash wahrscheinlich erfolgreich. Ggf. kann zuerst die Hard-Reset.uf2 Datei geflasht werden, welche den Controller zurücksetzt. Im Anschluss sollte wieder die normale Firmware geflasht werden.

Autodarts-Details:

F: Keine Tasten funktionieren innerhalb der Autodarts-Oberfläche.

A: Stelle sicher, dass das Browserfenster "fokussiert" ist (klicke in das Autodarts-Browserfenster).

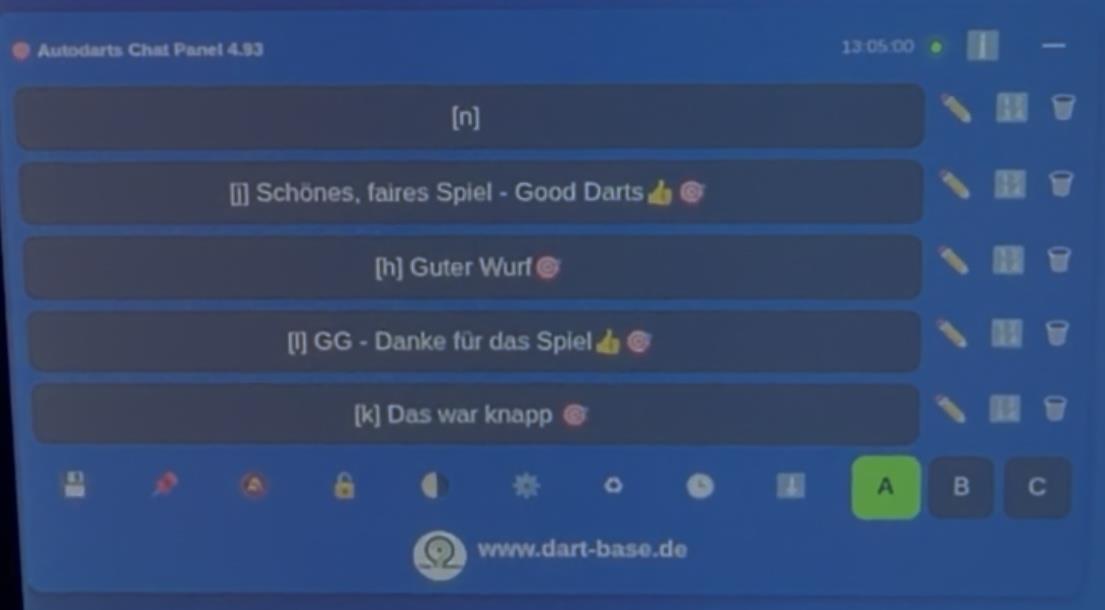
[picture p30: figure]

Autor: mrcl-rckl | 33 | Version: 1.0

Schnellchat-Funktion:

F: Wie benutze ich die Quick Chat Macros?

A: Stelle sicher, dass dieses Skript „Autodarts Chat Macro“ (https://greasyfork.org/de/scripts/562681-autodarts-chat-macro-overlay-panel-v4-93) in Tampermonkey (für Chrome hier (https://chromewebstore.google.com/detail/dhdgffkkebhmkfjojejmpbldmpobfkfo) herunterladen) installiert ist. Weise die Makros so den Tasten H, J, K und L zu.

Ist dein Problem immer noch nicht gelöst? Wenn du alle oben genannten Schritte überprüft hast und das Pad immer noch nicht funktioniert, besuche bitte die GitHub Repository Issues-Seite, um dein Problem zu melden oder nach von der Community beigesteuerten Lösungen zu suchen!

Autor: mrcl-rckl | 34 | Version: 1.0

# Firmware-Anpassung:

Das Autodarts Macropad ist vollständig anpassbar. Wenn du die Tastenzuweisung ändern oder neue Makros hinzufügen möchtest, kannst du die ZMK-Firmware anpassen. Da das Projekt auf GitHub gehostet wird, musst du keine Programmierwerkzeuge auf deinem PC installieren – die Firmware wird automatisch in der Cloud erstellt.

Die Konfiguration deiner Buttons wird in der Datei "keymap" gespeichert. Die Originalakte finden Sie unter dieser Adresse: https://github.com/mrcl-rckl/autodarts_macropad/blob/main/config/macro12.keymap (https://github.com/mrcl-rckl/autodarts_macropad/blob/main/config/macro12.keymap)

Wie man das Layout verändert:

- Das Repository forken: Gehe zur Hauptprojektseite: https://github.com/mrcl-rckl/autodarts_macropad. Klicken Sie oben rechts auf die Schaltfläche "Fork", um Ihre eigene Kopie des Projekts zu erstellen.
- Bearbeiten Sie die Keymap: Gehen Sie in Ihrem geforkten Repository zur config/macro12.keymap-Datei und klicken Sie auf das Bleistift-Symbol, um den Code direkt in Ihrem Browser zu bearbeiten.
- Keycodes ändern: Ersetzen Sie die bestehenden Befehle (z. B. &kp ENTER) durch die gewünschten Befehle.
- Beispiel: Um eine Belegung auf den Buchstaben "M" zu ändern, verwenden Sie &kp M.
- Commit & Build: Klicke auf "Commit changes" zum Speichern. Dies startet automatisch einen Build-Prozess im Tab "Actions" deines GitHub-Repositories.
- Download & Flash: Warte etwa 2–3 Minuten. Sobald der Build abgeschlossen ist (markiert durch ein grünes Häkchen), klicke darauf, scrolle nach unten und lade die Firmware herunter. Entpacke die Datei und flashe die .uf2-Datei wie auf Seite 23 beschrieben.

Nützliche Ressourcen:

- ZMK-Keycode-Referenz: Eine vollständige Liste aller verfügbaren Schlüssel (Medientasten, F-Tasten usw.) findest du hier: https://zmk.dev/docs/codes

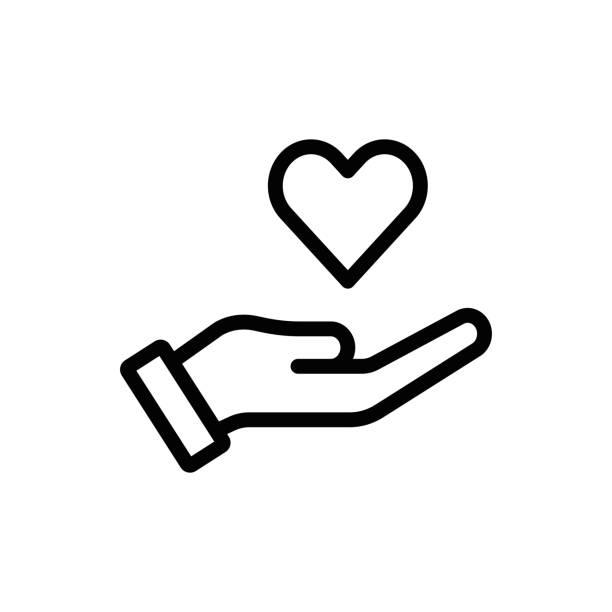
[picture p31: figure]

Autor: mrcl-rckl | 35 | Version: 1.0

# Danke für deine Spende:

# https://buymeacoffee.com/mrcl_rckl

## Wenn dieses DIY-Projekt bei dir ins Schwarze getroffen hat und dir der Bau gefallen hat, kannst du meine Arbeit gerne unterstützen. Jede Spende ist sehr willkommen und hilft mir, mehr Open-Source-Tools für die Community zu

entwickeln.

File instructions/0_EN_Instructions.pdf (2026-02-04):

English

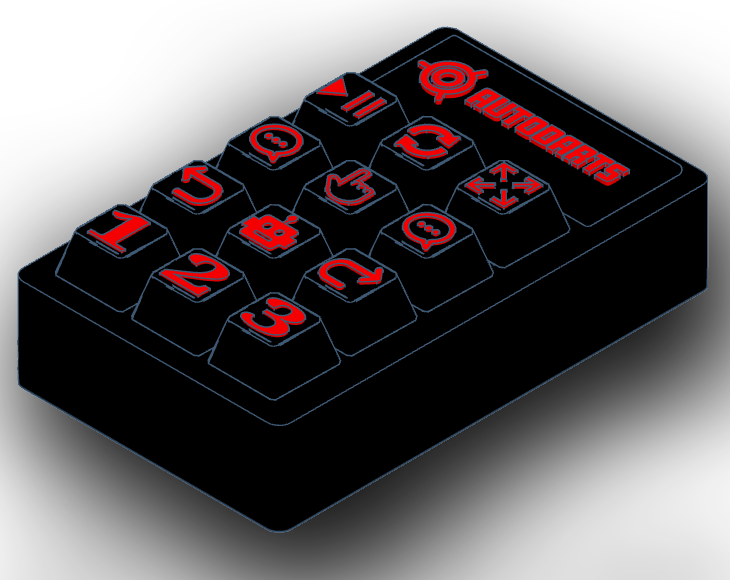
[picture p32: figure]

Author: mrcl-rckl | 1 | Version: 1.0

# DIY: 12 Key Macropad for Autodarts

Difficulty: Recommended for experienced makers

Requires 3D-Printing and soldering

Author: mrcl-rckl | 2 | Version: 1.0

# Table of contents:

Page(s) | Content
1 | Front page
2 | Table of contents
3 | Bill of materials
4 | Required tools & additional materials
5 | 3D-Printing
6-22 | Soldering & assembly
23-25 | Firmware installation and completion
26 | Testing
27 | Operation guide
28-30 | FAQ
31 | Firmware customization
32 | Thanks!

Author: mrcl-rckl | 3 | Version: 1.0

# Bill of materials:

- 12x GATERON G Pro 3.0 switches (color does not matter): https://de.aliexpress.com/item/1005007052507996.html
- 1x nRF52840 developer board (SuperMini): https://de.aliexpress.com/item/1005008664621573.html
- 1x 503030 500mAh battery (Larger one possible too, there's enough space): https://de.aliexpress.com/item/1005007964712378.html
- 12x 1N4148 diodes:
https://de.aliexpress.com/item/1005006208000285.html
- 16x Jumper wires female (minimum 20cm → 30cm recommended): https://de.aliexpress.com/item/1005007046465880.html
- 1x Toggle switch (not necessary, but recommended for longer battery life while in standby): https://de.aliexpress.com/item/4000032608294.html
- 1x ASUS USB-BT500 bluetooth 5.0 dongle adapter: https://www.cyberport.de/pc-undzubehoer/netzwerk/bluetooth/asus/pdp/4e18-007/asus-usb-bt500-bluetooth-5-0-usb-adapter.html (https://www.cyberport.de/pc-und-zubehoer/netzwerk/bluetooth/asus/pdp/4e18-007/asus-usb-bt500-bluetooth-5-0-usb-adapter.html)

Author: mrcl-rckl | 4 | Version: 1.0

# Required tools & additional materials:

- USB-C charging cable
- Solder wire
- Soldering iron
- Hot air gun ord lighter
- Heat shrinks
- Side cutters
- Pliers
- Wire stripping tool
- Super glue
- Filament - PLA or PETG or ... (2 different colors recommended)

Author: mrcl-rckl | 5 | Version: 1.0

# 3D-Printing:

Start by printing all provided models. If you are using a Bambu Lab printer, I recommend using the included .3mf files for optimized print settings and better results.

To achieve a dual-color look, a multi-color unit (like an AMS) is not required. You can simply insert a manual pause or a 'Filament Change' command in your slicer at the desired layer height. See: https://youtu.be/tKPWpWb8gBw The printer will stop at the designated point, allowing you to swap filament and resume the print.

To ensure the best print quality, do not crowd the build plate with all models at once. I recommend grouping the prints as follows:

- Batch 1: The main case and the back cover
- Batch 2: All 12 keycaps (can be printed together)
- Individual Runs: Print the logos separately to maintain high detail. The optional wall mount should also be printed on its own.

Files on Printables: https://www.printables.com/model/1576041-autodartsmacropad (https://www.printables.com/model/1576041-autodarts-macropad)

Files on MakerWorld: https://makerworld.com/de/models/2319788-autodartsmacropad (https://makerworld.com/de/models/2319788-autodarts-macropad)


Author: mrcl-rckl | 6 | Version: 1.0

# Soldering and assembly:

1. For the first four switches, begin by soldering a 15cm red lead to one of the contact pins. On the opposite pin, install a 1N4148 signal diode.
CRITICAL: Diode must be oriented in a "Switch-to-Row" configuration, meaning the black marking (cathode) must point away from the switch.
2. Snap the four pre-soldered switches into the housing, arranging them vertically to form the first column. Ensure each switch is firmly seated and flush with the mounting plate.

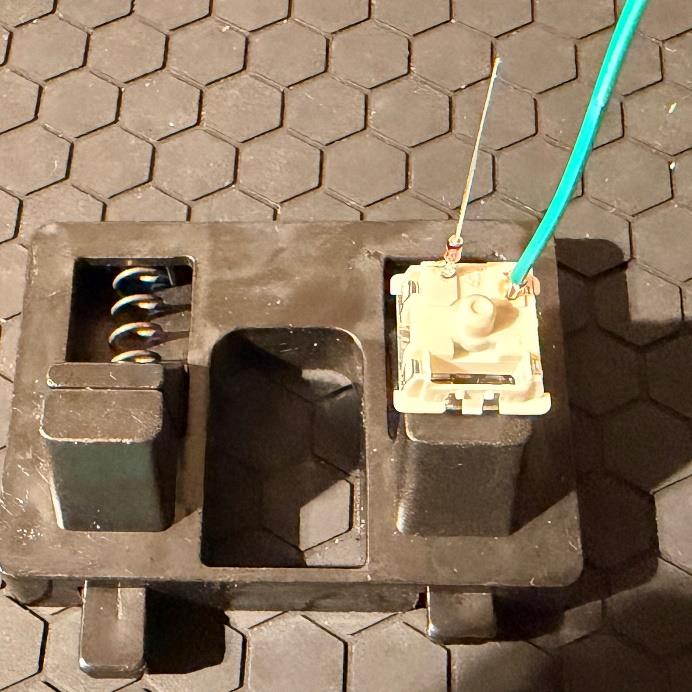
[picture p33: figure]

Author: mrcl-rckl | 7 | Version: 1.0
3. For the next four switches, begin by soldering a 15cm green lead to one of the contact pins. On the opposite pin, install a 1N4148 signal diode. CRITICAL: Diode must be oriented in a "Switch-to-Row" configuration, meaning the black marking (cathode) must point away from the switch.
4. Snap the four pre-soldered switches into the housing, arranging them vertically to form the first column. Ensure each switch is firmly seated and flush with the mounting plate.

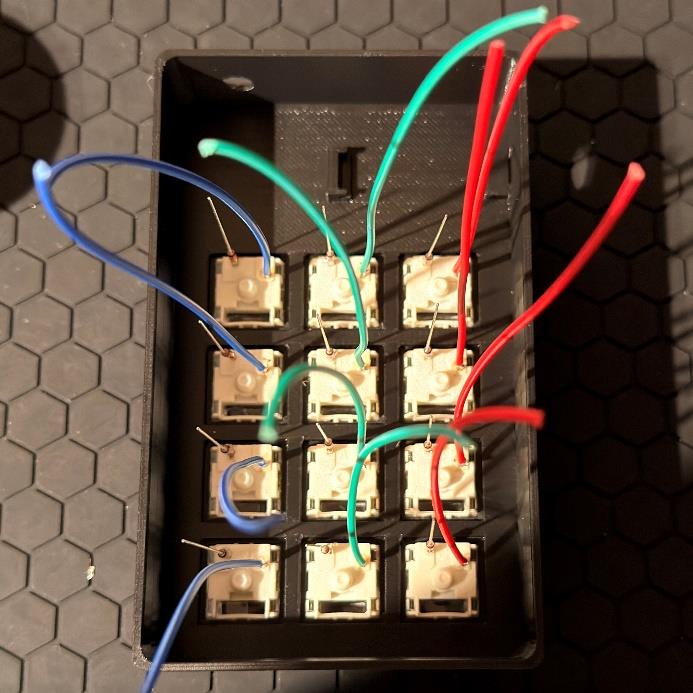
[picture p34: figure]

Author: mrcl-rckl | 8 | Version: 1.0
5. For the last four switches, begin by soldering a 15cm blue lead to one of the contact pins. On the opposite pin, install a 1N4148 signal diode.
CRITICAL: Diode must be oriented in a "Switch-to-Row" configuration, meaning the black marking (cathode) must point away from the switch.
6. Snap the four pre-soldered switches into the housing, arranging them vertically to form the first column. Ensure each switch is firmly seated and flush with the mounting plate.


Author: mrcl-rckl | 9 | Version: 1.0
7. Identify the top row, characterized by the extra space reserved for the nRF52840. Bridge the three diodes by bending the outer leads so they overlap at the center component. Utilizing pliers for this process ensures a precise, "factory-clean" finish and a more reliable solder joint.
8. Apply solder to the junction where the three cathode leads meet. Ensure the joint is clean and covers all three leads to establish a reliable row bus.


Author: mrcl-rckl | 10 | Version: 1.0
9. Use your side cutters (or flush cutters) to trim the lead of the middle diode to a length of approximately 8 mm. This will leave enough material for a secure connection for the next wire.
10. Solder a 20 cm orange wire with female connector to the trimmed end of the diode lead. This wire will serve as the main connection for your vertical column.


Author: mrcl-rckl | 11 | Version: 1.0
11. Repeat steps 7 through 10 for the second vertical column. However, substitute the orange wire with yellow wire. This color distinction will help you identify the columns correctly during the final wiring stage.
12. Repeat steps 7 through 10 for the third vertical column. However, substitute the orange wire with purple wire. This color distinction will help you identify the columns correctly during the final wiring stage.


Author: mrcl-rckl | 12 | Version: 1.0
13. Repeat steps 7 through 10 for the last vertical column. However, substitute the orange wire with brown wire. This color distinction will help you identify the columns correctly during the final wiring stage.
14. Gather all four red wires, strip the ends, and twist the copper strands together. Solder the bundle to create a single, secure termination point.

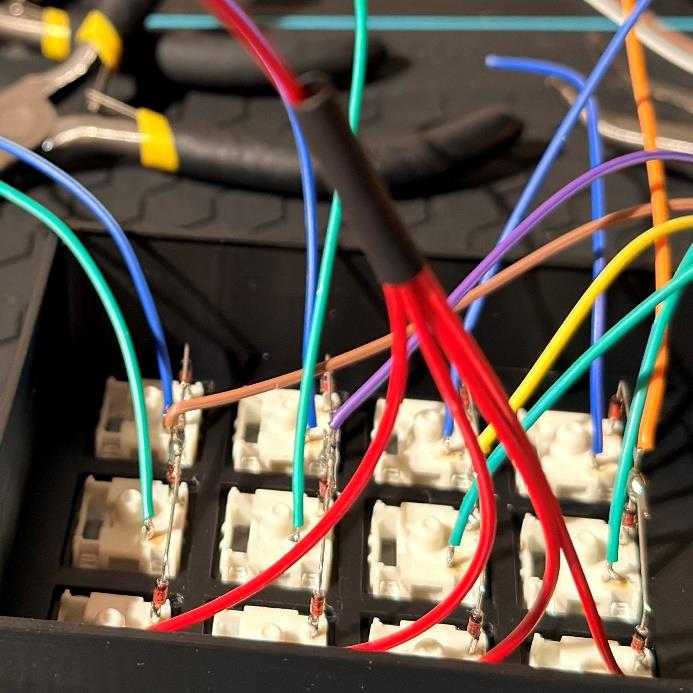
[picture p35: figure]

Author: mrcl-rckl | 13 | Version: 1.0
15. Prepare a 15 cm red wire equipped with a female connector. Slide a piece of heat-shrink tubing onto the wire before soldering. Solder the open end of this lead to the red wire bundle you created in the previous step.
16. Slide the heat-shrink tubing over the solder joint. Use a heat gun or a lighter to shrink the tubing until it forms a tight, secure seal around the connection.


Author: mrcl-rckl | 14 | Version: 1.0
17. Repeat steps 14–16 using green wire instead of red for the middle column. Ensure the solder joint is well-insulated with heat-shrink tubing as previously described.
18. Repeat steps 14–16 using blue wire instead of red for the last column. Ensure the solder joint is well-insulated with heat-shrink tubing as previously described.


Author: mrcl-rckl | 15 | Version: 1.0
19. Prepare the power switch by cutting a 30 cm female jumper wire in half. Strip a few millimeters of insulation from the cut ends and slide a piece of heat-shrink tubing onto each wire. Solder the two leads to the terminals of the toggle switch.
20. Slide the tubing over the solder joints and shrink them using a heat gun or a lighter for a fully insulated connection.


Author: mrcl-rckl | 16 | Version: 1.0

21.
a. Preparing the Battery: If your battery has a connector, cut it off. WARNING: Cut the wires one by one to prevent a short circuit. Do not allow the exposed ends to touch!
b. Connecting Toggle Switch: Strip the ends of the red battery wire and the open lead of the toggle switch. Slide a piece of heat-shrink tubing onto the battery's red (positive) wire, then solder it to the toggle switch leads.
c. Battery Ground Extension: Take a 15 cm black female jumper wire. Strip the insulation from the end and do the same for the battery's negative (black) lead. Slide your heat-shrink tubing onto the wire before soldering. Join the two black wires and solder them together to create a solid connection.
d. Insulation: Position both heat-shrink tubes over the solder joints and shrink them using hot air or a lighter to fully insulate the connections.

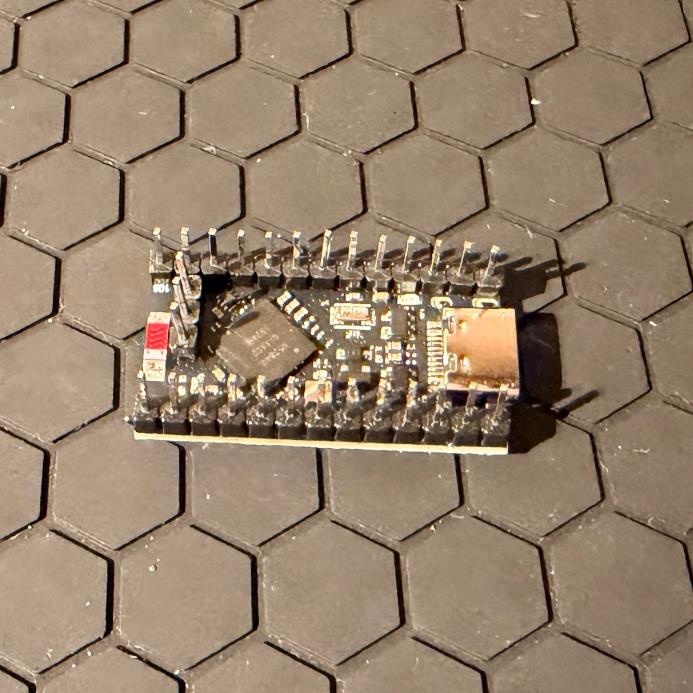
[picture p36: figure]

Author: mrcl-rckl | 17 | Version: 1.0
22. Unpack your microcontroller and solder the included male header pins to the board. Ensure the pins are perfectly vertical and the solder joints are clean, as these will be the connection points for all your female jumper wires.


Author: mrcl-rckl | 18 | Version: 1.0
23. Seat the controller into the housing by aligning it with the two retaining clips in the center of the case. You will need to apply some firm pressure near the USB-C port to slide the board down until the connector is perfectly aligned with the case opening.
Note: You may need to gently wiggle the controller to find the perfect position. Be careful not to apply excessive force to avoid damaging the MCU or the 3D-printed mounting tabs.
24. Now, connect the female jumpers to the controller’s header pins according to the provided wiring diagram and pinout images.

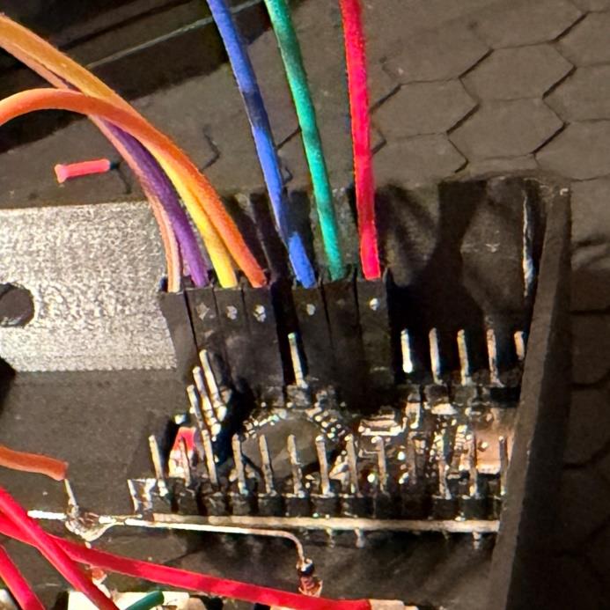
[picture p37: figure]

Author: mrcl-rckl | 19 | Version: 1.0

Important: Double-check that each row and column lead is connected to its designated GPIO pin. A single swapped wire will result in incorrect key presses or a non-responsive matrix.


Author: mrcl-rckl | 20 | Version: 1.0

Author: mrcl-rckl | 21 | Version: 1.0
25. Install the toggle switch into the designated mounting hole in the case. Connect the female leads (black and white) to the battery pads (B+ and B-) on the microcontroller as shown in the reference image.
Important: Double-check the polarity before connecting. Reversing the battery leads can permanently damage the charging circuit of nRF52840.

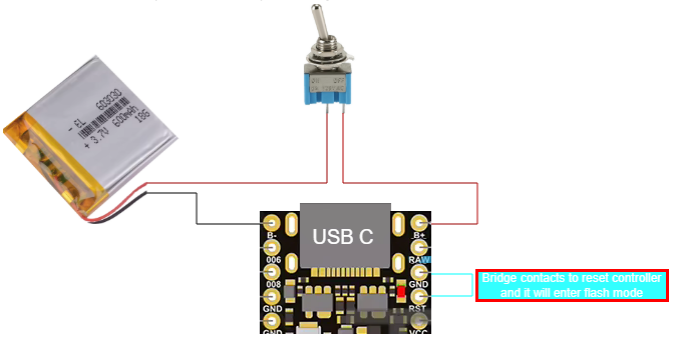
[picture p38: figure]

Author: mrcl-rckl | 22 | Version: 1.0

26.
a. Internal Power Test: Flip the toggle switch to ON. The onboard status LEDs should illuminate immediately.
b. USB Connection: Turn the switch OFF and connect the controller to your computer via USB-C. The LEDs will light up again, and your PC should recognize the device as a removable drive (e.g., NICENANO). Troubleshooting: > If the drive does not appear, you may need to manually trigger the Bootloader Mode: Disconnect the USB cable and ensure the power switch is OFF. Use a screwdriver or tweezers to carefully bridge the GND and RST pins. While holding the bridge, plug the USB cable back in.
CAUTION: Be extremely precise. Bridging the wrong pins could cause a short circuit and permanently damage the MCU.

Author: mrcl-rckl | 23 | Version: 1.0

27.
a. Install Firmware: Simply drag and drop (or copy/paste) the 6_Macropad_Firmware.uf2 file (Download here: https://github.com/mrcl-rckl/autodarts_macropad/releases/download/Autodarts/6_Macropad_Firmware.uf2) (https://github.com/mrcl-rckl/autodarts_macropad/releases/download/Autodarts/6_Macropad_Firmware.uf2) onto the controller's removable drive.
b. Auto-Restart: The MCU will automatically flash the firmware and restart. The drive will disconnect and disappear from your computer. Note: To re-flash in the future, you must manually enter bootloader mode again by bridging the GND and RST pins.
c. Bluetooth Pairing: Unplug the USB-C cable and toggle the power switch to ON. Your macropad is now discoverable as a Bluetooth keyboard in the settings of your Autodarts system.

28.
a. Power Management Note: To preserve battery longevity, ensure the device is always powered OFF via the toggle switch when not in use.
b. Charging Instructions: To charge the battery, the toggle switch must be in the ON position. If the switch is off, the charging circuit will be disconnected and the battery will not receive power from the USB-C port.
c. Battery Life Efficiency: Thanks to the low power consumption of the nRF52840, the battery is designed to last approximately 6 weeks on a single charge under normal usage conditions.
d. Pairing with a New Device: To pair the macropad with a different computer or system: Turn the toggle switch ON and wait a few seconds for the device to initialize. Press and hold [Arrow Left] + [Arrow Right] simultaneously for 5 seconds. This will clear the existing Bluetooth bonds, and the pad will become discoverable again in your new device's Bluetooth settings.

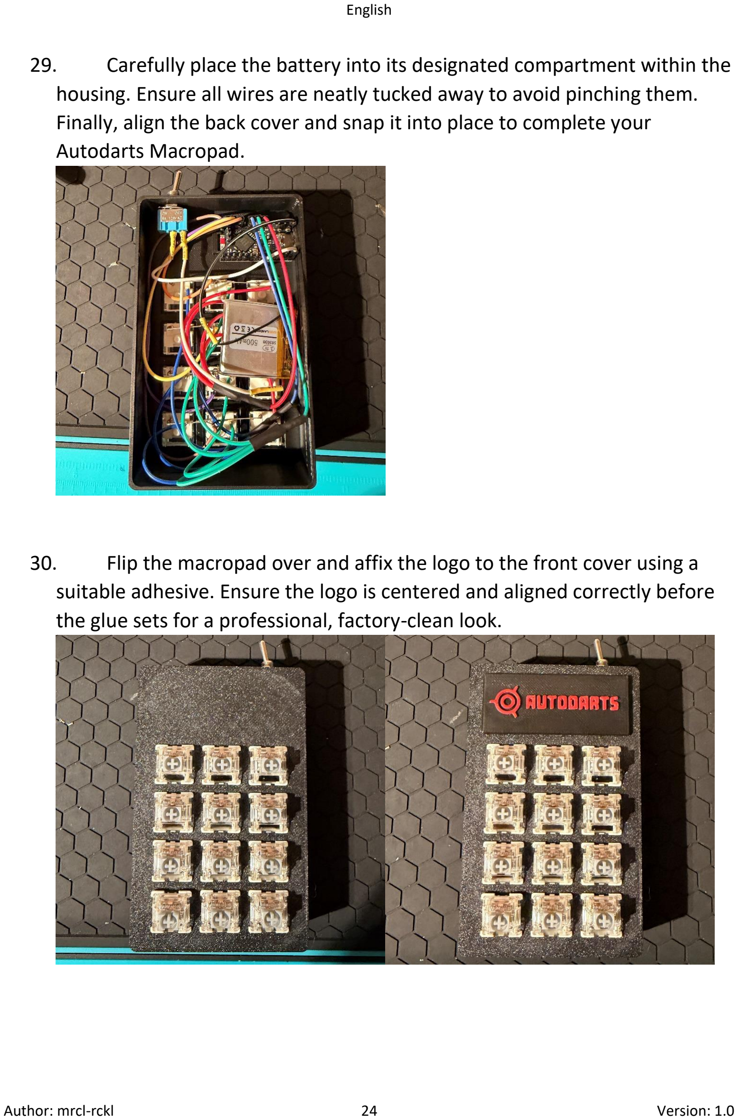
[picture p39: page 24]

Author: mrcl-rckl | 24 | Version: 1.0
29. Carefully place the battery into its designated compartment within the housing. Ensure all wires are neatly tucked away to avoid pinching them. Finally, align the back cover and snap it into place to complete your Autodarts Macropad.
30. Flip the macropad over and affix the logo to the front cover using a suitable adhesive. Ensure the logo is centered and aligned correctly before the glue sets for a professional, factory-clean look.

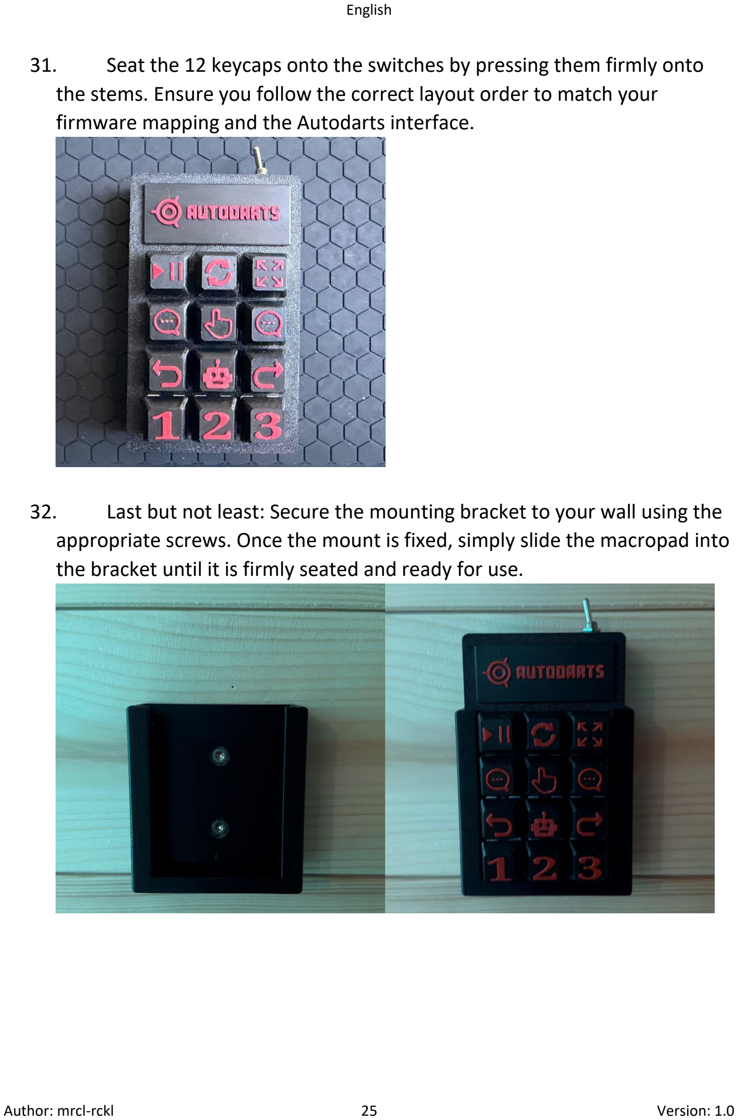
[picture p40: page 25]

Author: mrcl-rckl | 25 | Version: 1.0
31. Seat the 12 keycaps onto the switches by pressing them firmly onto the stems. Ensure you follow the correct layout order to match your firmware mapping and the Autodarts interface.
32. Last but not least: Secure the mounting bracket to your wall using the appropriate screws. Once the mount is fixed, simply slide the macropad into the bracket until it is firmly seated and ready for use.

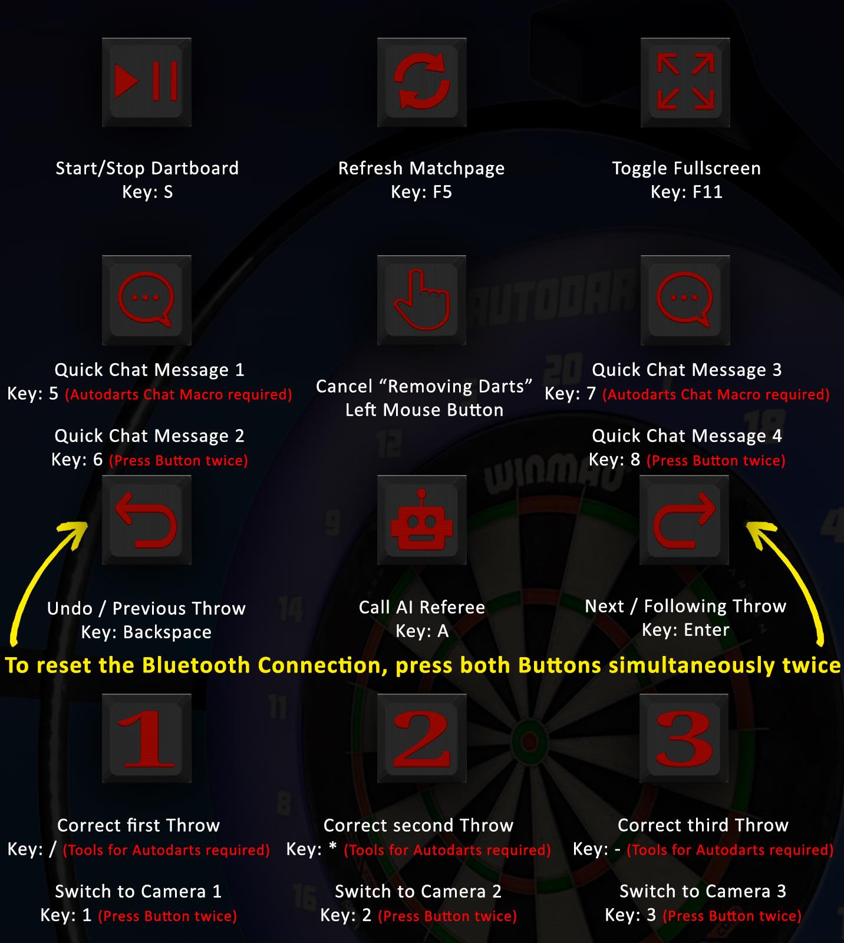
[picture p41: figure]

Author: mrcl-rckl | 26 | Version: 1.0

# Testing:

Refer to the following image for the specific key assignments. To verify that every switch is working correctly and mapped to the right command, navigate to the Online Keyboard Tester and actuate each key on your new macropad: https://www.onlinemictest.com/de/tastatur-test/

Important: Board Reset hotkey is not yet supported in Autodarts

Author: mrcl-rckl | 27 | Version: 1.0

# Operation guide:

1. Powering the Device Power On/Off: Use the physical toggle switch located on the side/back of the case. Energy Saving: To maximize battery longevity, it is recommended to switch the device OFF when not in use, even though the nRF52840 features a low-power deep sleep mode.
2. Monitoring Battery Levels The Autodarts Macropad reports its battery percentage directly to your operating system via the Bluetooth HID profile. You do not need to rely on internal LEDs. On Windows (10/11): Navigate to Settings > Bluetooth & devices. Locate the "Autodarts Macropad" in the list. The battery percentage will be displayed directly next to the device name. On Linux (GNOME/KDE): Open your System Settings and go to the Power or Bluetooth section. The battery status will be listed under "Devices" or "Input Devices." Command Line (Advanced): You can also use the command upower -e to find the device path and upower -i [path] to see the exact percentage.
3. Charging Instructions Requirement: The toggle switch must be in the ON position to charge the battery. If the switch is off, the charging circuit is physically disconnected and the battery will not charge via USB-C. Charging Source: You can charge the device using any standard USB-C cable connected to a computer or a 5V power adapter. Runtime: A full charge typically lasts about 6 weeks depending on usage.
4. Pairing & Resetting Bluetooth If you need to connect the macropad to a new computer or system, you must clear the existing Bluetooth "bonds": Ensure the device is powered ON. Press the [Arrow Left] and [Arrow Right] keys simultaneously twice. The device will clear its memory and enter pairing mode. It will now be discoverable again in your system's Bluetooth settings.

Author: mrcl-rckl | 28 | Version: 1.0

# FAQ:

Connectivity & Bluetooth:

Q: My computer cannot find the "Autodarts Macropad" via Bluetooth.

A: First, ensure the toggle switch is in the ON position. If it is on and still not appearing, your macropad might still be bonded to another device. Perform a Bluetooth Reset by holding [Arrow Left] + [Arrow Right] for 5 seconds, then refresh your computer's Bluetooth search.

Q: The connection feels laggy or keys are repeating.

A: Bluetooth signals can be affected by interference. Ensure there are no large metal objects or high-powered 2.4GHz routers directly between the pad and your computer. If you are using a desktop PC, ensure your Bluetooth antenna is connected.

Power & Battery:

Q: I’ve had the pad plugged into USB-C for hours, but the battery is still empty.

A: Crucial Check: Is your toggle switch turned ON? Due to the hardware design, the battery only connects to the charging circuit when the switch is in the ON position. It will not charge if the device is switched off.

Q: The device works via USB, but turns off as soon as I unplug the cable.

A: Check the solder joints on the B+ and B- pins of the microcontroller and the battery leads. Also, ensure the toggle switch wiring is secure. If a wire has come loose, the battery power cannot reach the MCU.

Author: mrcl-rckl | 29 | Version: 1.0

Key Inputs & Hardware:

Q: One specific key is not registering at all.

A: This is usually a hardware issue. Check the solder joints on that specific switch. Check the diode orientation. If the diode is soldered backward, the signal will be blocked. Verify the connection between the row/column wire and the MCU pin.

Q: When I press one key, the wrong character appears on the screen.

A: Your physical wiring likely doesn't match the GPIO pins defined in the firmware. Double-check your wiring against the Wiring Diagram on page 29. If you swapped a row or column wire, the layout will be mirrored or shifted.

Firmware & Flashing:

Q: The controller does not appear as a "NICENANO" or "Removable Drive" when plugged in.

A: Use a different USB-C cable; many cables are "charge-only" and do not carry data. If the cable is good, you must manually enter Bootloader Mode by quickly bridging the GND and RST pins with a screwdriver while the device is connected to your PC.

Q: I flashed the .uf2 file, but nothing changed.

A: Ensure the file transfer finished completely before the drive disconnected. If the drive disappears immediately after dropping the file, the flash was likely successful. Perform a Bluetooth reset (Arrow L+R) to ensure the new mapping is active.

Author: mrcl-rckl | 30 | Version: 1.0

Autodarts Specifics:

Q: No keys are working within the Autodarts interface.

A: Ensure your browser window is "in focus" (click inside the Autodarts window). Browsers block keyboard inputs to background tabs for security reasons.

Quick Chat Function:

Q: How do I use the quick Chat Macros?

A: Ensure to install this script https://greasyfork.org/de/scripts/562681-autodartschat-macro-overlay-panel-v4-93 (https://greasyfork.org/de/scripts/562681-autodarts-chat-macro-overlay-panel-v4-93) into Tampermonkey (download here for Chrome: https://chromewebstore.google.com/detail/dhdgffkkebhmkfjojejmpbldmpobfkfo) Assign the Macros like this to keys 5, 6, 7 and 8.

Is your problem still not solved? If you’ve checked all the steps above and the pad still isn't behaving, please visit the GitHub Repository Issues page to report your problem or look for community-contributed solutions!

Author: mrcl-rckl | 31 | Version: 1.0

# Firmware Customization:

The Autodarts Macropad is fully customizable. If you want to change the key assignment or add new macros, you can modify the ZMK firmware. Since the project is hosted on GitHub, you don't need to install any coding tools on your PC—the firmware is built automatically in the cloud.

The configuration of your buttons is stored in the "keymap" file. You can find the original file at this address: https://github.com/mrcl-rckl/autodarts_macropad/blob/main/config/macro12.keymap (https://github.com/mrcl-rckl/autodarts_macropad/blob/main/config/macro12.keymap)

How to modify the Layout:

- Fork the repository: Go to the main project page: https://github.com/mrcl-rckl/autodarts_macropad. (https://github.com/mrcl-rckl/autodarts_macropad) Click the "Fork" button in the top right to create your own copy of the project.
- Edit the Keymap: In your forked repository, navigate to the config/macro12.keymap file and click the pencil icon to edit the code directly in your browser.
- Change Keycodes: Replace the existing commands (e.g., &kp ENTER) with your desired ones.
- Example: To change a key to the letter "M", use &kp M.
- Commit & Build: Click "Commit changes" to save. This automatically starts a build process in the "Actions" tab of your GitHub repository.
Pro Tip: Always check the "Actions" tab after committing your changes. If the build turns red, there is a syntax error in your code (like a missing semicolon). You can click on the failed build to see exactly which line caused the error.
- Download & Flash: Wait about 2–3 minutes. Once the build is finished (indicated by a green checkmark), click on it, scroll down to "Artifacts", and download the firmware. Unzip the file and flash the .uf2 file as described on page 23.

Useful Resources:

- ZMK Keycode Reference: A full list of all available keys (Media keys, F-keys, etc.) can be found here: https://zmk.dev/docs/codes
- Visual Keymap Editor: If you prefer a graphical interface over editing text, you can use this web tool: https://nickcoutsos.github.io/keymap-editor/

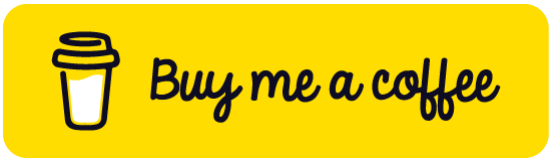
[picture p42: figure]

Author: mrcl-rckl | 32 | Version: 1.0

# Thanks for your Donation:

# https://buymeacoffee.com/mrcl_rckl

## If this DIY project hit the bullseye for you and you enjoyed the build, feel free to support my work. Any donation is greatly appreciated and helps me develop more open-

source tools for the community.

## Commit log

2026-03-17 Change Bluetooth power and mouse configuration
    Disable Bluetooth mouse functions.
    Reduce Bluetooth transmission power
2026-03-17 Change binding from LCLK to R in macro12.keymap
    Change to Finger to R / Reset the Board
